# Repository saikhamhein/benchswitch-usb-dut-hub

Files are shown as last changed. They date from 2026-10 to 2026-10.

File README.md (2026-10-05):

# BenchSwitch USB DUT Hub

A four-port USB 2.0 DUT hub for embedded firmware development and automated hardware testing.

BenchSwitch was born from a practical need in agentic firmware development: let the development workflow power-cycle a device instead of waiting for someone to unplug it. The design combines a USB2514B hub controller with individually switched downstream power, targeting host control through tools such as `uhubctl`.

**Prototype: hardware testing is pending.** See the [build guide](doc/BUILD.md), [design constraints](doc/DESIGN_CONSTRAINTS.md) and [bring-up checklist](doc/BRINGUP.md) before building or powering a board.

## Hardware

- Four USB-A DUT ports and one USB-B upstream connection
- Per-port CH217A power switching and overcurrent signalling
- Regulated 12–24 V DC input with buck conversion
- Design targets: 1 A per port, 2 A shared DUT current
- 95 × 80 mm, four-layer PCB
- KiCad 10.0.6 sources; 131 fitted components across 41 catalog groups

## Build

Open [BenchSwitch_USB_DUT_Hub.kicad_pro](PCB/BenchSwitch_USB_DUT_Hub.kicad_pro) in KiCad 10.0.6.

- [Schematic](doc/PCB_Schematic_R5_LCSC.pdf) and [assembly drawing](doc/PCB_Assembly_R5_LCSC.pdf)
- [Gerber ZIP](manufacturing/R5_LCSC/DIN_USB_Hub_A8_R5_LCSC_Gerber.zip)
- [Exact component BOM](manufacturing/R5_LCSC/assembly/BOM_exact_per_reference.csv) and [per-board procurement list](manufacturing/R5_LCSC/LCSC_PROCUREMENT_PER_BOARD.csv)

With Python 3.9+, verify the release files or export to a new directory:

```sh
python manufacturing/tools/verify_release.py
python manufacturing/tools/export_manufacturing.py --output build/manufacturing
```

## Files

- `PCB/`: native design, symbols, footprints and models
- `manufacturing/`: fabrication files, BOM and build tools
- `doc/`: drawings, assembly guidance and test procedures

[CAD verification](doc/VERIFICATION.json) · [Third-party notices and optional model downloads](doc/THIRD_PARTY.md)

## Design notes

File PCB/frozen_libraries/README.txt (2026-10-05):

Frozen library definitions for this design

Only the symbol and footprint definitions used by the reviewed design are included. Project-local library entries deliberately bind these names to the frozen copies, avoiding unintended changes when opening the project with KiCad 10.0.6.

Do not bulk-update the existing footprints or symbols from new global libraries merely to migrate file formats. When adding new parts, extend these frozen libraries deliberately or use a separate library name. The complete standard catalog is not included here.

Native board geometry and embedded schematic symbols remain authoritative. The applicable KiCad library copyright and license notices are included alongside these files.

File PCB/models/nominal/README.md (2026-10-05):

# Nominal component models

These drawing-derived models represent R5-LCSC component packages and terminal datums. Cosmetic features, internal connector contacts and production markings are simplified. They are not manufacturer-certified CAD or maximum-clearance envelopes.

The public PCB retains its circuit, copper, placement and selected parts. Optional Phoenix and Wurth vendor visuals were omitted from this release because redistribution rights were not established. This affects the 3D view only: the Phoenix input terminal and four ordered XUNPU USB-A connectors remain in the PCB and BOM.

Use purchased-part dimensions and the build/bring-up requirements for physical checks. See [third-party notes](../../../doc/THIRD_PARTY.md).

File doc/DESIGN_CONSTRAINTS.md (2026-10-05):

# BenchSwitch USB DUT Hub: design constraints

This summarizes the retained **R5-LCSC prototype** design basis. Preserve its circuit, placement, copper, drills and frozen manufacturing data. CAD integrity checks and component screens are not measured electrical/thermal qualification. The target remains **1 A per port, 2 A shared DUT current, regulated 12–24 V input**.

## Preserve the electrical layout

- Keep continuous inner ground planes and anchored outer ground fills; do not split digital and buck grounds.
- Preserve local input-bypass return to GND/exposed pad, six external regulator thermal vias, compact switch-node copper, short bootstrap return and quiet feedback return. The external-via arrangement does not inherit the vendor's under-exposed-pad reference-board thermal resistance.
- Preserve broad raw-output and protected-supply manifolds, the lower distribution bus, 2 mm right-edge feed and parallel layer transfers. Narrow sensing/bias/package escapes are not substitutes for the main high-current path.
- Keep the local 100 nF port-switch input bypasses and four nominal 10 µF input capacitors. Preserve the crystal's 1/3 resonator and 2/4 ground mapping and the selected 2.0 × 1.2 mm lands.
- Preserve USB data geometry and its eleven `USB_ESCAPE` rule areas. The reviewed outer-ground clearance was at least 0.500 mm to data tracks; the upstream through-hole data pads have approximately 0.450 mm minimum clearance. This is geometry evidence, not controlled-impedance or signal-integrity certification.
- Both 0.30/0.50 mm and 0.30/0.60 mm drill/land vias exist. The smaller lands have 0.10 mm nominal annular rings; do not represent all vias as 0.60 mm lands.

## Exact sourcing constraints

Use `PCB/SELECTED_COMPONENTS.json` and the frozen BOM for all references. The five R5-LCSC replacement groups cover 30 fitted references without changing their electrical connections or physical placement:

- Ordinary 10 kΩ group: **Yageo RC0603FR-0710KL / C98220**, 15 resistors, 1%, 0603, 0.1 W at 70 °C, ±100 ppm/°C. These do not replace tighter-tolerance feedback resistors; apply normal power/temperature derating.
- C20/C27: **Yageo CC0402KRX7R8BB104 / C105883**, 100 nF, 25 V, ±10%, X7R, 0402. C20 bypasses 3V3 and C27 HOST_VBUS; these parts are not the 24 V input capacitors or raw-output bank.
- Q11–Q14: **onsemi MMBT3904LT1G / C81464**, SOT-23 NPN, pin 1 base / 2 emitter / 3 collector, 40 V, 200 mA continuous. Emitters are grounded; 10 kΩ collector pullups to 5V_SYS and 10 kΩ base resistors/100 kΩ pulldowns are retained. Normal collector current is approximately 0.5 mA.
- C64–C69/C82–C83: **Samsung CL31B106KBHNFNE / C913957**, eight 10 µF/50 V/±10%/X7R/1206 ceramics. Keep the Samsung lands and the three Aishi 220 µF/50 V bulk capacitors. Nominally similar capacitance, voltage and package labels alone do not qualify alternatives.
- L6: **MetalLions MNR8065T100MT / C18222125**, 10 µH ±20%. The retained Sunlord-named footprint is a compatible land/envelope, not MetalLions-supplied CAD: two 2.2 × 7.5 mm pads with 3.8 mm inner gap; body maximum 8.3 × 8.3 × 6.5 mm.

J11–J14 remain XUNPU USB-231-ARY / C720525. A visual connector model must not become a BOM substitution.

## Output-capacitor screen

The selected Samsung part has the same 141-point typical DC-bias dataset as the prior CL31B106KBHNNNE. At 5.1 V, interpolated typical capacitance is 8.4357 µF per part. Eight parts multiplied by 0.90 tolerance, 0.85 temperature and 0.85 engineering reserve give **43.8826 µF**. The bias data are typical 25 °C, 1 kHz, 1 Vrms reference data; the reserve is an assumption. The result is voltage-dependent, not a universal minimum-capacitance or transient guarantee. The complete ceramic/polymer network still requires loop and load-release tests.

Do not automatically substitute TDK CGA5L1X7R1H106KT0Y0N or a generic 10 µF/50 V/X7R/1206. Exact ordering-code equivalence, bias behavior, lands and maximum body clearance require review.

## Inductor and fault screen

The selected MetalLions row specifies 44 mΩ maximum DCR and 13 MHz minimum SRF. Its published **8.00 A saturation / 3.20 A heat** entries appear under manufacturer **Max.** headings and must not be relabeled as guaranteed minima; 8.90/3.70 A are typical. Test data are at 20 °C: saturation is about 30% inductance drop and heat current about 40 °C rise. Operating range is −40 to +125 °C including self-heating. No guaranteed hot saturation or L(T,I) lower bound is established.

The SCT2433 high-side peak limit at 24 V is 4.25/5.00/5.75 A minimum/typical/maximum. A screening case uses 5.088 V output, 2.204 A total converter load and 479.4 kHz (510 kHz × 0.94). At assumed 4.48 µH, ideal CCM ripple gives approximately **3.137 A peak and 2.269 A RMS**. The 4.48 µH includes tolerance and assumed temperature/bias factors, not a guaranteed inductance bound. Current-limit delay, overshoot, core/AC loss and board thermal effects remain unbounded by that calculation; hot overload and normal-load testing are required.

Do not substitute the shorter SWPA8040S100MT or MNR8040T100MT merely because the pads fit: their published 3.6 A saturation rating is below the regulator fault-limit range. A different larger inductor requires its own primary-data, footprint and routing review. Component screens cannot certify hot fault immunity, loop stability or mounting-temperature limits.

## Verification boundary

Fresh KiCad 10.0.6 checks of the final sources on 5 October 2026 reported zero ERC findings, zero DRC violations, zero unconnected items and zero schematic-parity findings under inherited settings, including seven disabled DRC and four disabled ERC check types. Cleanup changed project naming, synchronized the embedded/source USB-A default-footprint metadata and removed optional 3D bindings; electrical connections, placed parts, copper and frozen manufacturing payloads were preserved. These checks do not establish actual connector fit, board temperatures, voltage transients, automatic-placement calibration or production qualification. Revalidate any hardware change and complete [prototype bring-up](BRINGUP.md).

### Configured checks excluded from the passing result

The [source-hash-bound verification summary](VERIFICATION.json) records the actual KiCad 10.0.6 result. The following check types were ignored; zero findings does not claim these checks passed:

- ERC: `single_global_label`, `four_way_junction`, `simulation_model_issue`, `footprint_filter`.
- DRC: `missing_courtyard`, `track_not_centered_on_via`, `tuning_profile_track_geometries`, `footprint_filters_mismatch`, `pth_inside_courtyard`, `npth_inside_courtyard`, `footprint_type_mismatch`.

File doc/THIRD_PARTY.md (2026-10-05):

# Third-party and component-model notices

The native PCB and schematic are the design sources. 3D models are visual aids; they do not establish part interchangeability, physical fit, clearance or electrical qualification.

## KiCad libraries

The frozen symbols and footprints include KiCad-derived material. The KiCad community attribution and full CC-BY-SA 4.0 terms with the electronic-design exception are retained in:

- [Symbol notices](../PCB/frozen_libraries/kicad-symbols-COPYRIGHT.txt)
- [Footprint notices](../PCB/frozen_libraries/kicad-footprints-COPYRIGHT.txt)

These notices also apply to KiCad-derived portions of custom footprints, including the AOS TO-252 and Samsung 1206 adaptations. Custom library naming does not imply that every definition is entirely original. Preserve attribution and applicable share-alike obligations when redistributing library material. The electronic-design exception is stated in the included notices; it is not a blanket relicensing of a library collection.

## KiCad 3D assets

Keep the copyright and licensing headers embedded in each retained STEP file.

- `D_SMC.step` and `D_SOD-123F.step` carry **GPL-3.0-or-later** with an electronic-design exception. The [GPL-3.0 text](../PCB/3d_models/GPL-3.0.txt) accompanies them. Their embedded exception says that embedding the symbol or unaltered portions into a design does not by itself make the resulting design GPL-covered; it does not invalidate other reasons the design may be covered. Their exact exception text remains in each model.
- Other retained KiCad package STEP files carry their embedded **CC-BY-SA 4.0 with electronic-design exception** notices. The full CC-BY-SA terms are included in the library notices above.

The retained files are not relicensed by this project. Frozen footprint templates were modified only to remove inherited nonlocal 3D-model references; the Phoenix custom footprint also has its optional vendor-model bindings removed. Footprint pads and other 2D geometry are unchanged. The USB-A default footprint name was synchronized in the source library and embedded schematic symbol to the retained XUNPU footprint already used by all four placed USB-A connectors; symbol pin definitions and placed instance footprints are unchanged.

## Project-created models

Nominal and display models are simplified, drawing-derived package geometry rather than manufacturer-certified solids. Features such as internal contacts, draft, markings and finish may be omitted. Use component datasheets and physical measurements for engineering decisions.

## Omitted optional vendor CAD

The public release excludes the optional Wurth USB-A and Phoenix terminal/mating-plug vendor solids, their PCB/footprint model bindings and populated STEP aggregates. Redistribution rights for those recovered solids were not established for this public package. The native 2D footprint pads, copper, placement, component identities and frozen manufacturing payloads remain unchanged.

Consequently, those components may be absent from a 3D view. The purchased USB-A parts remain **XUNPU USB-231-ARY / C720525**, and the input terminal and mating plug remain the Phoenix parts specified in the exact BOM/accessory list. No replacement-part compatibility is claimed.

## Project license

No project-wide open-source license has been selected. Public availability does not replace third-party terms or grant a new blanket license to the original project material.

## Optional vendor-model downloads

The electrical project opens and the supplied fabrication package can be used without these optional 3D visuals. For a local visualization, obtain CAD directly from the manufacturer and follow the terms shown with the download:

- [Wurth WR-USB Standard](https://www.we-online.com/en/components/products/INPUT_OUTPUT_WR_USB_STANDARD): select **614004190021** and its STP download. This is a visualization surrogate, not the ordered XUNPU USB-A part.
- [Phoenix Contact MSTBA 2,5/2-G-5,08, 1757242](https://www.phoenixcontact.com/en-us/products/pcb-header-mstba-25-2-g-508-1757242): product CAD/downloads for the PCB header; [original model download](https://www.phoenixcontact.com/product/product/MTc1NzI0Mg/downloads/7966887?_realm=us&_locale=en-US).
- [Phoenix Contact MSTB 2,5/2-ST-5,08, 1757019](https://www.phoenixcontact.com/en-us/products/pcb-plug-mstb-25-2-st-508-1757019): product CAD/downloads for the mating plug; [original model download](https://www.phoenixcontact.com/product/product/MTc1NzAxOQ/downloads/8194525?_realm=us&_locale=en-US).

Add any locally downloaded file through KiCad's footprint 3D-model settings and check orientation, origin and alignment yourself. A newer vendor download may differ from the former private model; no alignment or interchangeability is assumed. Keep private downloads outside the published source tree unless redistribution permission is established. Do not modify pads, placement, copper or the frozen Gerbers just to improve a render.

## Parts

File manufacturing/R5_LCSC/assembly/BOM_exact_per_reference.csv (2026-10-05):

Reference | Value | Footprint | MPN | LCSC
C1 | 4.7u / 16V | Capacitor_SMD:C_0805_2012Metric | 0805B475K160NT | C880382
C2 | 4.7u / 16V | Capacitor_SMD:C_0805_2012Metric | 0805B475K160NT | C880382
C4 | 4.7u / 16V | Capacitor_SMD:C_0805_2012Metric | 0805B475K160NT | C880382
C10 | 100nF | Capacitor_SMD:C_0603_1608Metric | CC0603KRX7R9BB104 | C14663
C11 | 100nF | Capacitor_SMD:C_0603_1608Metric | CC0603KRX7R9BB104 | C14663
C12 | 33pF C0G | Capacitor_SMD:C_0603_1608Metric | CL10C330JB8NNNC | C1663
C13 | 33pF C0G | Capacitor_SMD:C_0603_1608Metric | CL10C330JB8NNNC | C1663
C14 | 100nF | Capacitor_SMD:C_0603_1608Metric | CC0603KRX7R9BB104 | C14663
C20 | 100nF | Capacitor_SMD:C_0402_1005Metric | CC0402KRX7R8BB104 | C105883
C21 | 100nF | Capacitor_SMD:C_0603_1608Metric | CC0603KRX7R9BB104 | C14663
C22 | 100nF | Capacitor_SMD:C_0603_1608Metric | CC0603KRX7R9BB104 | C14663
C23 | 100nF | Capacitor_SMD:C_0603_1608Metric | CC0603KRX7R9BB104 | C14663
C24 | 100nF | Capacitor_SMD:C_0603_1608Metric | CC0603KRX7R9BB104 | C14663
C25 | 100nF | Capacitor_SMD:C_0603_1608Metric | CC0603KRX7R9BB104 | C14663
C26 | 4.7uF / 16V | Capacitor_SMD:C_0805_2012Metric | 0805B475K160NT | C880382
C27 | 100nF / 25V | Capacitor_SMD:C_0402_1005Metric | CC0402KRX7R8BB104 | C105883
C60 | 4.7u / 50V | Capacitor_SMD:C_1206_3216Metric | 1206B475K500NT | C29823
C61 | 4.7u / 50V | Capacitor_SMD:C_1206_3216Metric | 1206B475K500NT | C29823
C63 | 100n / 50V | Resistor_SMD:R_0603_1608Metric | CC0603KRX7R9BB104 | C14663
C64 | 10u / 50V | DUT_Custom:Samsung_CL31_1206 | CL31B106KBHNFNE | C913957
C65 | 10u / 50V | DUT_Custom:Samsung_CL31_1206 | CL31B106KBHNFNE | C913957
C66 | 10u / 50V | DUT_Custom:Samsung_CL31_1206 | CL31B106KBHNFNE | C913957
C67 | 10u / 50V | DUT_Custom:Samsung_CL31_1206 | CL31B106KBHNFNE | C913957
C68 | 10u / 50V | DUT_Custom:Samsung_CL31_1206 | CL31B106KBHNFNE | C913957
C69 | 10u / 50V | DUT_Custom:Samsung_CL31_1206 | CL31B106KBHNFNE | C913957
C70 | 100n / 50V | Resistor_SMD:R_0603_1608Metric | CC0603KRX7R9BB104 | C14663
C71 | 100n / 50V | Capacitor_SMD:C_0603_1608Metric | CC0603KRX7R9BB104 | C14663
C72 | 4.7u / 50V | Capacitor_SMD:C_1206_3216Metric | 1206B475K500NT | C29823
C73 | 47u / 50V | Capacitor_THT:CP_Radial_D6.3mm_P2.50mm | SPZ1HM470E08O00RAXXX | C122243
C74 | 220u / 50V polymer | Capacitor_THT:CP_Radial_D10.0mm_P5.00mm | SPZ1HM221G12O00RAXXX | C2691846
C76 | 220u / 50V polymer | Capacitor_THT:CP_Radial_D10.0mm_P5.00mm | SPZ1HM221G12O00RAXXX | C2691846
C77 | 220u / 50V polymer | Capacitor_THT:CP_Radial_D10.0mm_P5.00mm | SPZ1HM221G12O00RAXXX | C2691846
C80 | 4.7u / 50V | Capacitor_SMD:C_1206_3216Metric | 1206B475K500NT | C29823
C82 | 10u / 50V | DUT_Custom:Samsung_CL31_1206 | CL31B106KBHNFNE | C913957
C83 | 10u / 50V | DUT_Custom:Samsung_CL31_1206 | CL31B106KBHNFNE | C913957
C101 | 100nF | Capacitor_SMD:C_0603_1608Metric | CC0603KRX7R9BB104 | C14663
C102 | 10uF / 16V | Capacitor_SMD:C_0805_2012Metric | CC0805KKX7R7BB106 | C326595
C103 | 220uF / 10V | Capacitor_THT:CP_Radial_D6.3mm_P2.50mm | ERS1AM221E11OT | C106640
C104 | 100nF | Capacitor_SMD:C_0603_1608Metric | CC0603KRX7R9BB104 | C14663
C201 | 100nF | Capacitor_SMD:C_0603_1608Metric | CC0603KRX7R9BB104 | C14663
C202 | 10uF / 16V | Capacitor_SMD:C_0805_2012Metric | CC0805KKX7R7BB106 | C326595
C203 | 220uF / 10V | Capacitor_THT:CP_Radial_D6.3mm_P2.50mm | ERS1AM221E11OT | C106640
C204 | 100nF | Capacitor_SMD:C_0603_1608Metric | CC0603KRX7R9BB104 | C14663
C301 | 100nF | Capacitor_SMD:C_0603_1608Metric | CC0603KRX7R9BB104 | C14663
C302 | 10uF / 16V | Capacitor_SMD:C_0805_2012Metric | CC0805KKX7R7BB106 | C326595
C303 | 220uF / 10V | Capacitor_THT:CP_Radial_D6.3mm_P2.50mm | ERS1AM221E11OT | C106640
C304 | 100nF | Capacitor_SMD:C_0603_1608Metric | CC0603KRX7R9BB104 | C14663
C401 | 100nF | Capacitor_SMD:C_0603_1608Metric | CC0603KRX7R9BB104 | C14663
C402 | 10uF / 16V | Capacitor_SMD:C_0805_2012Metric | CC0805KKX7R7BB106 | C326595
C403 | 220uF / 10V | Capacitor_THT:CP_Radial_D6.3mm_P2.50mm | ERS1AM221E11OT | C106640
C404 | 100nF | Capacitor_SMD:C_0603_1608Metric | CC0603KRX7R9BB104 | C14663
D6 | SMCJ24CA / bidir | Diode_SMD:D_SMC | SMCJ24CA-13-F | C135155
D7 | 12V gate clamp | Diode_SMD:D_SOD-123F | BZT52H-C12,115 | C282531
D8 | STPS5L60S | Diode_SMD:D_SMC | STPS5L60S | C140620
D101 | GREEN / VBUS | DUT_Custom:LED_LiteOn_LTST-S270KGKT_SideView | LTST-S270KGKT | C125113
D201 | GREEN / VBUS | DUT_Custom:LED_LiteOn_LTST-S270KGKT_SideView | LTST-S270KGKT | C125113
D301 | GREEN / VBUS | DUT_Custom:LED_LiteOn_LTST-S270KGKT_SideView | LTST-S270KGKT | C125113
D401 | GREEN / VBUS | DUT_Custom:LED_LiteOn_LTST-S270KGKT_SideView | LTST-S270KGKT | C125113
F1 | 5 A / Nano2 | Fuse:Fuse_Littelfuse-NANO2-451_453 | 0451005.MRL | C48467
J1 | 12-24V DC / pluggable | DUT_Custom:Phoenix_MSTBA_1757242_2pos_P5.08 | 1757242 | C90074
J2 | XUNPU USB-B10-BRW | DUT_Custom:XUNPU_USB_B10_BRW | USB-B10-BRW | C720549
J11 | USB-231-ARY | DUT_Custom:XUNPU_USB_231_ARY | USB-231-ARY | C720525
J12 | USB-231-ARY | DUT_Custom:XUNPU_USB_231_ARY | USB-231-ARY | C720525
J13 | USB-231-ARY | DUT_Custom:XUNPU_USB_231_ARY | USB-231-ARY | C720525
J14 | USB-231-ARY | DUT_Custom:XUNPU_USB_231_ARY | USB-231-ARY | C720525
L6 | 10uH / MNR8065T | DUT_Custom:Sunlord_SWPA8065S | MNR8065T100MT | C18222125
Q6 | AOD409 / -60V P-MOS | DUT_Custom:AOS_AOD409_TO252 | AOD409 | C36220
Q11 | MMBT3904 | Package_TO_SOT_SMD:SOT-23 | MMBT3904LT1G | C81464
Q12 | MMBT3904 | Package_TO_SOT_SMD:SOT-23 | MMBT3904LT1G | C81464
Q13 | MMBT3904 | Package_TO_SOT_SMD:SOT-23 | MMBT3904LT1G | C81464
Q14 | MMBT3904 | Package_TO_SOT_SMD:SOT-23 | MMBT3904LT1G | C81464
R1 | 100k 1% | Resistor_SMD:R_0603_1608Metric | 0603WAF1003T5E | C25803
R2 | 100k 1% | Resistor_SMD:R_0603_1608Metric | 0603WAF1003T5E | C25803
R10 | 100k | Resistor_SMD:R_0603_1608Metric | 0603WAF1003T5E | C25803
R11 | 100k | Resistor_SMD:R_0603_1608Metric | 0603WAF1003T5E | C25803
R12 | 100k | Resistor_SMD:R_0603_1608Metric | 0603WAF1003T5E | C25803
R13 | 100k | Resistor_SMD:R_0603_1608Metric | 0603WAF1003T5E | C25803
R14 | 12k 1% | Resistor_SMD:R_0603_1608Metric | 0603WAF1202T5E | C22790
R15 | 10k | Resistor_SMD:R_0603_1608Metric | RC0603FR-0710KL | C98220
R60 | 10k | Resistor_SMD:R_0603_1608Metric | RC0603FR-0710KL | C98220
R61 | 100k 1% | Resistor_SMD:R_0603_1608Metric | 0603WAF1003T5E | C25803
R62 | 13k 1% | Resistor_SMD:R_0603_1608Metric | 0603WAF1302T5E | C22797
R65 | 53.6k 0.1% | Resistor_SMD:R_0603_1608Metric | ERA-3AEB5362V | C2074540
R66 | 10k 0.1% | Resistor_SMD:R_0603_1608Metric | RT0603BRD0710KL | C95204
R69 | 6.8k 0.1% | Resistor_SMD:R_0603_1608Metric | RT0603BRD076K8L | C861539
R70 | 2k 0.1% | Resistor_SMD:R_0603_1608Metric | PTFR0603B2K00P9 | C328425
R71 | 10k bleed | Resistor_SMD:R_0603_1608Metric | RC0603FR-0710KL | C98220
R72 | 100R | Resistor_SMD:R_0603_1608Metric | 0603WAF1000T5E | C22775
R101 | 100k | Resistor_SMD:R_0603_1608Metric | 0603WAF1003T5E | C25803
R102 | 10k | Resistor_SMD:R_0603_1608Metric | RC0603FR-0710KL | C98220
R103 | 51k 1% | Resistor_SMD:R_0603_1608Metric | 0603WAF5102T5E | C23196
R104 | 470R / 0.5W | Resistor_SMD:R_0805_2012Metric | ERJ-P06F4700V | C441978
R105 | 4.7k 1% | Resistor_SMD:R_0603_1608Metric | 0603WAF4701T5E | C23162
R106 | 10k 1% | Resistor_SMD:R_0603_1608Metric | RC0603FR-0710KL | C98220
R107 | 10k 1% | Resistor_SMD:R_0603_1608Metric | RC0603FR-0710KL | C98220
R201 | 100k | Resistor_SMD:R_0603_1608Metric | 0603WAF1003T5E | C25803
R202 | 10k | Resistor_SMD:R_0603_1608Metric | RC0603FR-0710KL | C98220
R203 | 51k 1% | Resistor_SMD:R_0603_1608Metric | 0603WAF5102T5E | C23196
R204 | 470R / 0.5W | Resistor_SMD:R_0805_2012Metric | ERJ-P06F4700V | C441978
R205 | 4.7k 1% | Resistor_SMD:R_0603_1608Metric | 0603WAF4701T5E | C23162
R206 | 10k 1% | Resistor_SMD:R_0603_1608Metric | RC0603FR-0710KL | C98220
R207 | 10k 1% | Resistor_SMD:R_0603_1608Metric | RC0603FR-0710KL | C98220
R301 | 100k | Resistor_SMD:R_0603_1608Metric | 0603WAF1003T5E | C25803
R302 | 10k | Resistor_SMD:R_0603_1608Metric | RC0603FR-0710KL | C98220
R303 | 51k 1% | Resistor_SMD:R_0603_1608Metric | 0603WAF5102T5E | C23196
R304 | 470R / 0.5W | Resistor_SMD:R_0805_2012Metric | ERJ-P06F4700V | C441978
R305 | 4.7k 1% | Resistor_SMD:R_0603_1608Metric | 0603WAF4701T5E | C23162
R306 | 10k 1% | Resistor_SMD:R_0603_1608Metric | RC0603FR-0710KL | C98220
R307 | 10k 1% | Resistor_SMD:R_0603_1608Metric | RC0603FR-0710KL | C98220
R401 | 100k | Resistor_SMD:R_0603_1608Metric | 0603WAF1003T5E | C25803
R402 | 10k | Resistor_SMD:R_0603_1608Metric | RC0603FR-0710KL | C98220
R403 | 51k 1% | Resistor_SMD:R_0603_1608Metric | 0603WAF5102T5E | C23196
R404 | 470R / 0.5W | Resistor_SMD:R_0805_2012Metric | ERJ-P06F4700V | C441978
R405 | 4.7k 1% | Resistor_SMD:R_0603_1608Metric | 0603WAF4701T5E | C23162
R406 | 10k 1% | Resistor_SMD:R_0603_1608Metric | RC0603FR-0710KL | C98220
R407 | 10k 1% | Resistor_SMD:R_0603_1608Metric | RC0603FR-0710KL | C98220
U1 | AP2112K-3.3 | Package_TO_SOT_SMD:SOT-23-5 | AP2112K-3.3TRG1 | C51118
U2 | USBLC6-2SC6 | Package_TO_SOT_SMD:SOT-23-6 | USBLC6-2SC6 | C7519
U3 | USB2514B-AEZC-TR | Package_DFN_QFN:QFN-36-1EP_6x6mm_P0.5mm_EP3.7x3.7mm | USB2514B-AEZC-TR | C16251
U4 | APX803S00-31SR | DUT_Custom:Diodes_APX803S_SR_SOT23 | APX803S00-31SR-7 | C2067620
U6 | SCT2433STER | DUT_Custom:SCT2433_ESOP8 | SCT2433STER | C509399
U7 | ETA7014S2G | Package_TO_SOT_SMD:SOT-23-6 | ETA7014S2G | C7465500
U11 | CH217A | Package_TO_SOT_SMD:SOT-23-6 | CH217A | C54973763
U12 | CH217A | Package_TO_SOT_SMD:SOT-23-6 | CH217A | C54973763
U13 | CH217A | Package_TO_SOT_SMD:SOT-23-6 | CH217A | C54973763
U14 | CH217A | Package_TO_SOT_SMD:SOT-23-6 | CH217A | C54973763
U21 | USBLC6-2SC6 | Package_TO_SOT_SMD:SOT-23-6 | USBLC6-2SC6 | C7519
U22 | USBLC6-2SC6 | Package_TO_SOT_SMD:SOT-23-6 | USBLC6-2SC6 | C7519
U23 | USBLC6-2SC6 | Package_TO_SOT_SMD:SOT-23-6 | USBLC6-2SC6 | C7519
U24 | USBLC6-2SC6 | Package_TO_SOT_SMD:SOT-23-6 | USBLC6-2SC6 | C7519
Y1 | 24MHz / CL20pF | DUT_Custom:YXC_YSX531SL_5032 | XL1EL89CSI-111YLC-24M | C18214302

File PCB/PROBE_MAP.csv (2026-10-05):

Reference | Net | Local_X_mm | Local_Y_down_mm | Pad_diameter_mm | Note
TP1 | /VIN_DC | 92.0 | 10.0 | 1.0 | Use short ground spring
TP10 | 3V3 | 53.8 | 45.0 | 1.0 | Use short ground spring
TP11 | GND | 48.0 | 39.0 | 1.0 | Use short ground spring
TP2 | /VIN_PROTECTED | 78.0 | 28.5 | 1.0 | Use short ground spring
TP3 | /5V_BUCK | 55.5 | 44.0 | 1.0 | Use short ground spring
TP4 | 5V_SYS | 57.0 | 48.0 | 1.0 | Use short ground spring
TP5 | /OV5_SENSE | 64.0 | 41.9 | 1.0 | Use short ground spring
TP6 | /BUCK_FB | 72.2 | 33.0 | 0.4 | High-resistance low-capacitance probe only; prefer rail measurement
TP7 | GND | 73.7 | 29.8 | 1.0 | Use short ground spring
TP8 | GND | 55.0 | 46.6 | 1.0 | Use short ground spring
TP9 | GND | 57.0 | 44.0 | 1.0 | Use short ground spring

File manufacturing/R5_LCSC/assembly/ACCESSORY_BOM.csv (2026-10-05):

MPN | LCSC | Quantity | Description | Price_snapshot_USD | Status
1757019 | C90073 | 1 | Phoenix removable mating plug supplied separately or mated | 0.8795 | Not placed by CPL; confirm delivery handling before purchase

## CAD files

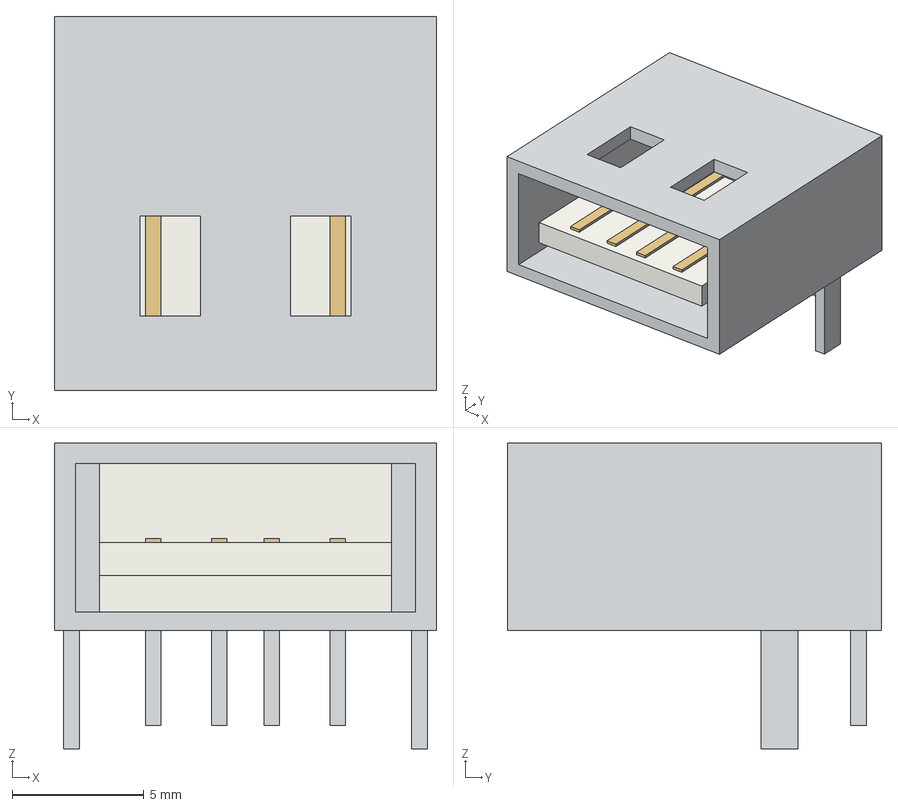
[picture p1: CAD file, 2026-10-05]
PCB/models/display/XUNPU_USB_231_ARY_display.step
14.5 x 14.2 x 11.6 mm
insulator
rear_insulator
contact_1
tail_1
contact_2
tail_2
contact_3
tail_3
contact_4
tail_4
shield_tail_0
shield_tail_1

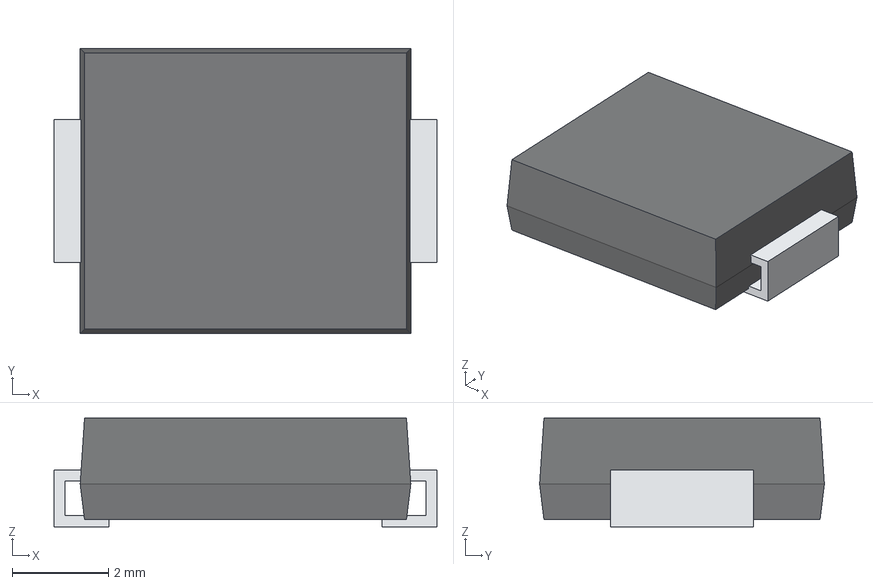
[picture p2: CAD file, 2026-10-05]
PCB/models/nominal/SMCJ24CA_bidir_nominal.step
7.94 x 5.91 x 2.25 mm
Molded_body_no_polarity_band
Terminal_1
Terminal_2

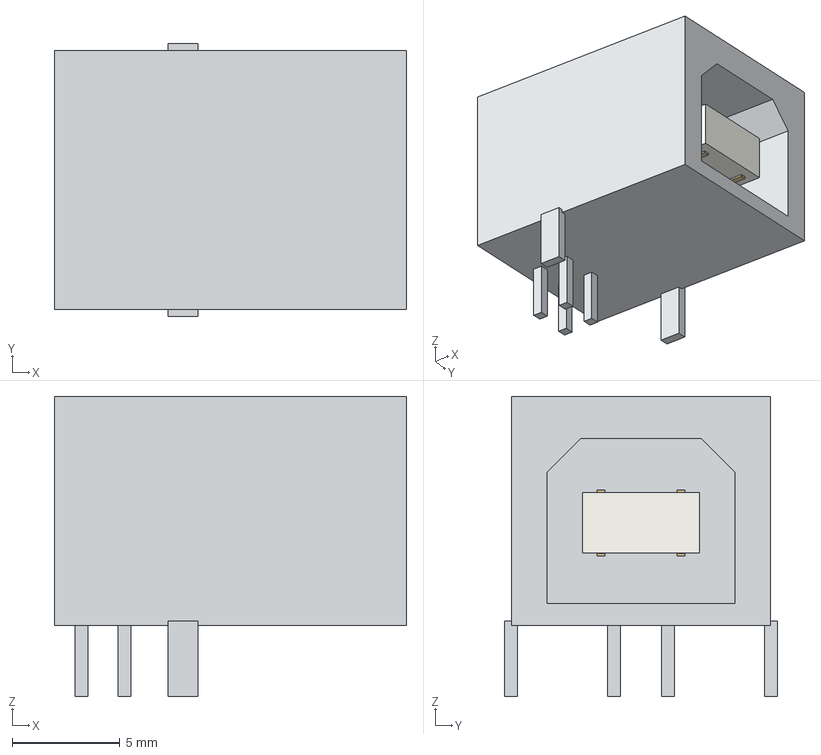
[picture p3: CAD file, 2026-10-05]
PCB/models/display/XUNPU_USB_B10_BRW_display.step
16.3 x 12.6 x 13.9 mm
rear_insulator
central_insulator
tail_1
tail_2
tail_3
tail_4
shield_tail_0
shield_tail_1
contact_1
contact_2
contact_3
contact_4

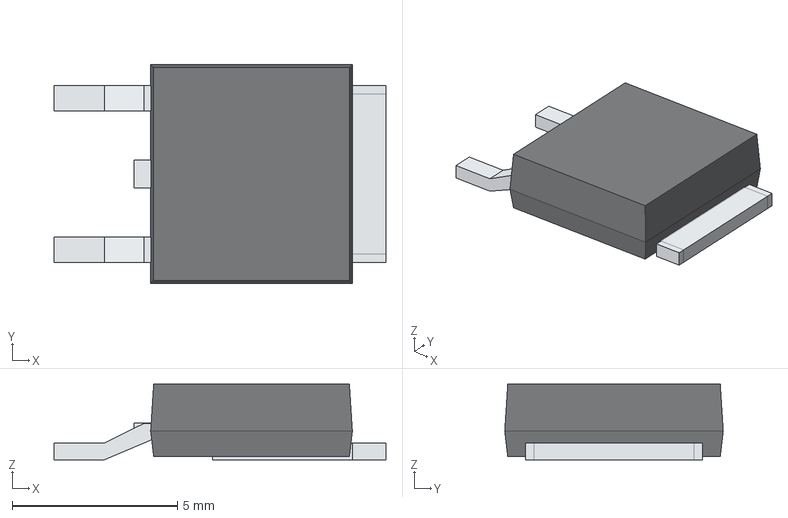
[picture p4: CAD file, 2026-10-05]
PCB/models/nominal/AOD409_TO252_nominal.step
10.0 x 6.60 x 2.29 mm
Molded_body
Drain_tab_2
Gate_1
Source_3
Trimmed_drain_lead_2

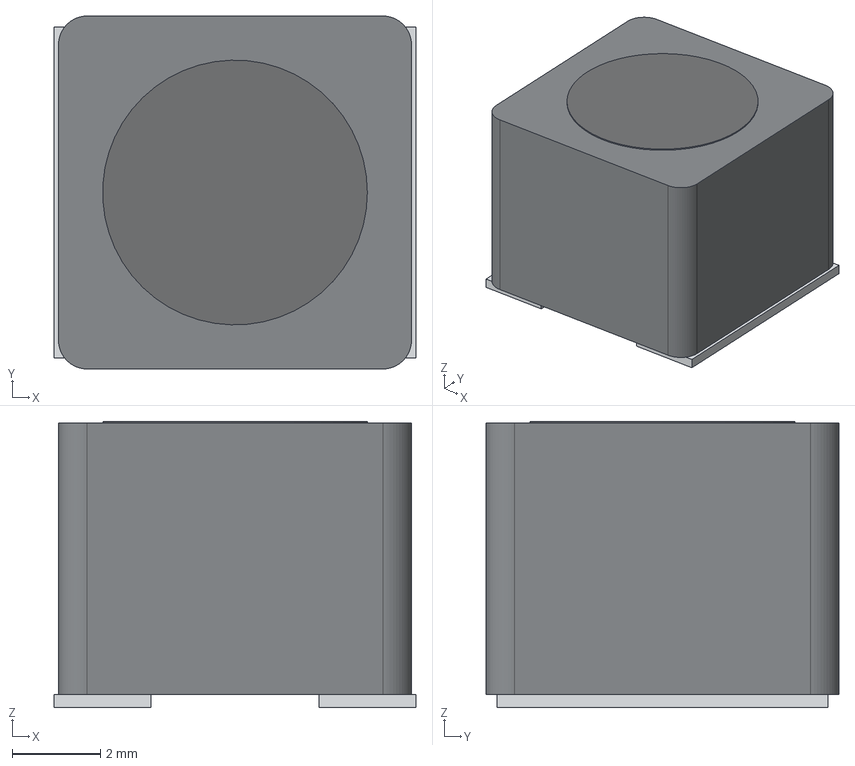
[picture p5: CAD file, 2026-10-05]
PCB/models/display/Sunlord_SWPA8065S_display.step
8.20 x 8.00 x 6.49 mm
ferrite
top_core
termination_1
termination_2

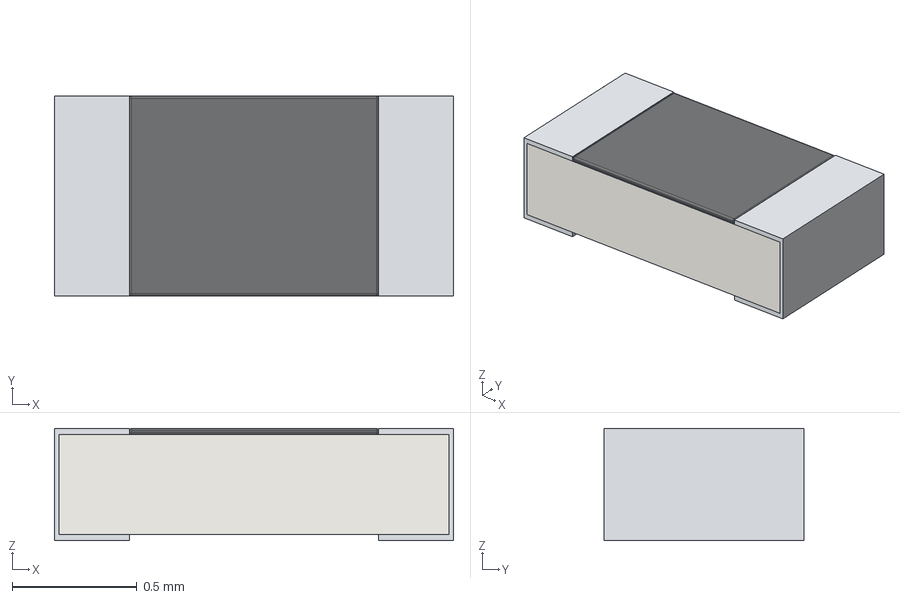
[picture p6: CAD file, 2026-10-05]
PCB/models/nominal/0603WAF_nominal.step
1.60 x 0.8 x 0.45 mm
Alumina_substrate
Resistive_overcoat_no_text
Termination_1
Termination_2

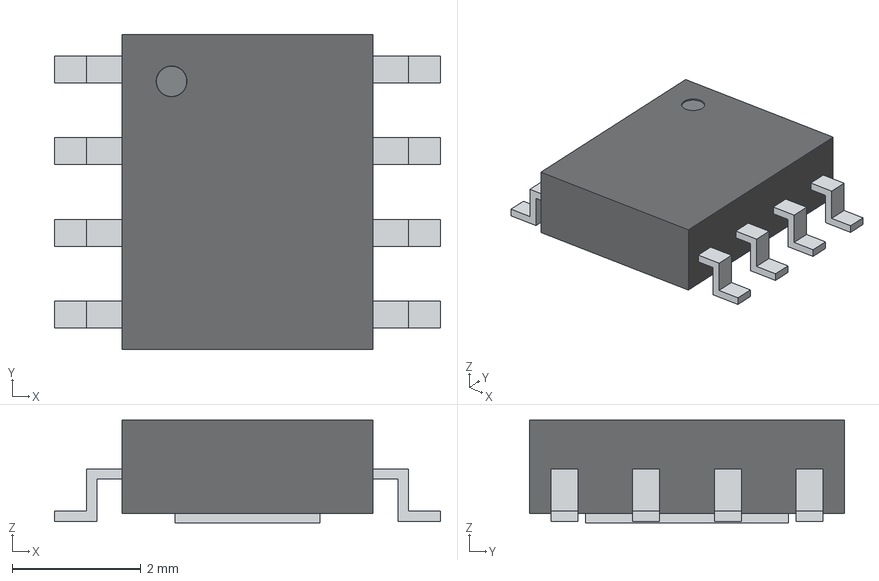
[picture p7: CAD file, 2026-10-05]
PCB/models/display/SCT2433_ESOP8_display.step
6.00 x 4.90 x 1.60 mm
moulding
pin1_recess
exposed_pad
lead_-1_0
lead_-1_1
lead_-1_2
lead_-1_3
lead_1_0
lead_1_1
lead_1_2
lead_1_3

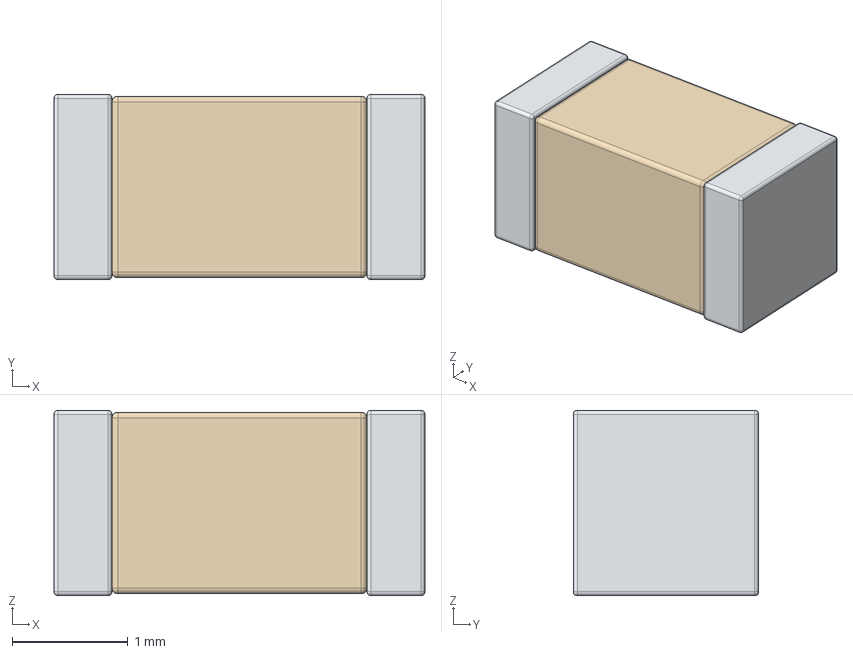
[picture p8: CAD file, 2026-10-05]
PCB/models/nominal/CL31B106KBHNFNE_nominal.step
3.20 x 1.60 x 1.60 mm
Ceramic_nominal
Termination_1
Termination_2

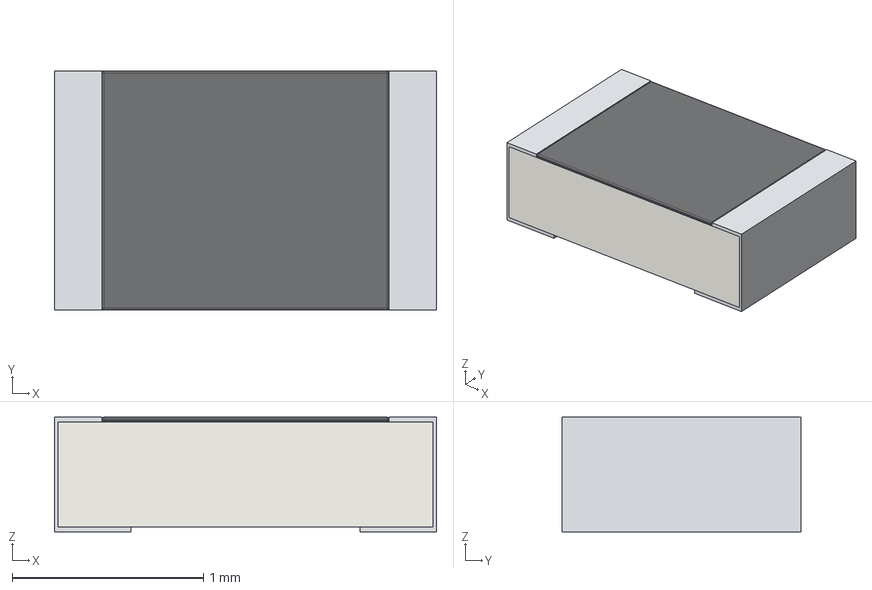
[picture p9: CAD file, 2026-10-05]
PCB/models/nominal/ERJ_P06F4700V_nominal.step
2.00 x 1.25 x 0.6 mm
Alumina_substrate
Resistive_overcoat_no_text
Termination_1
Termination_2

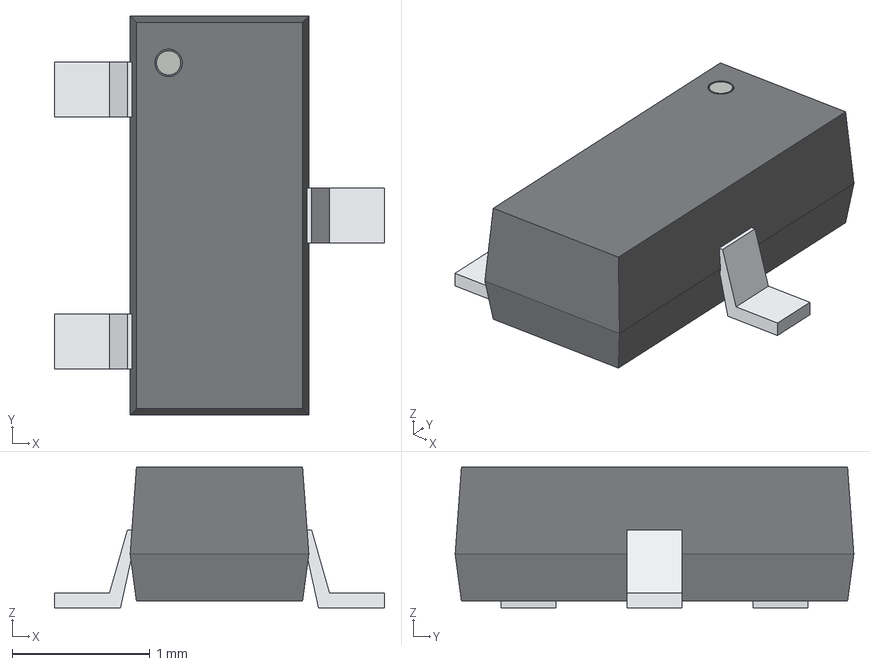
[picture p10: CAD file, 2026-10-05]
PCB/models/nominal/APX803S_SR_nominal.step
2.40 x 2.90 x 1.02 mm
Pin1_orientation_dot_schematic
Molded_body
Lead_1
Lead_2
Lead_3

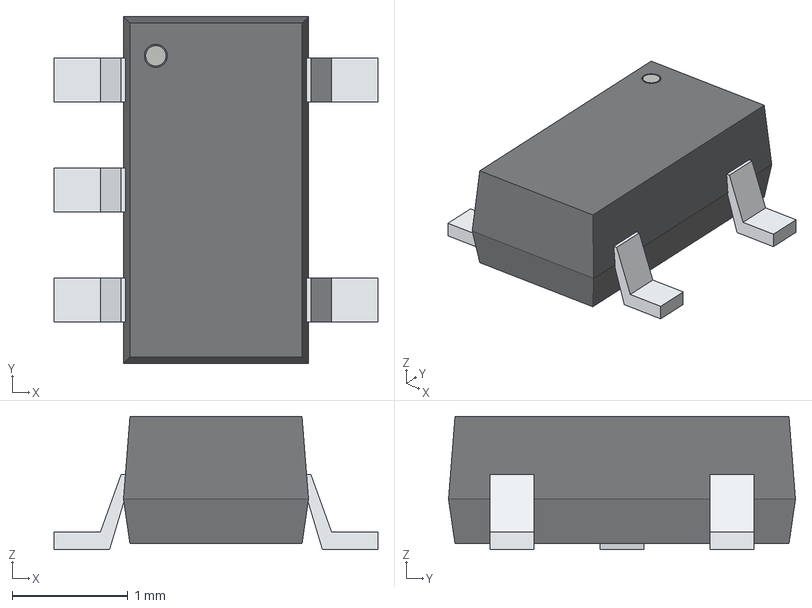
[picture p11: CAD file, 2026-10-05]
PCB/models/nominal/AP2112K_nominal.step
2.80 x 3.00 x 1.15 mm
Pin1_orientation_dot_schematic
Molded_body
Lead_1
Lead_2
Lead_3
Lead_4
Lead_5

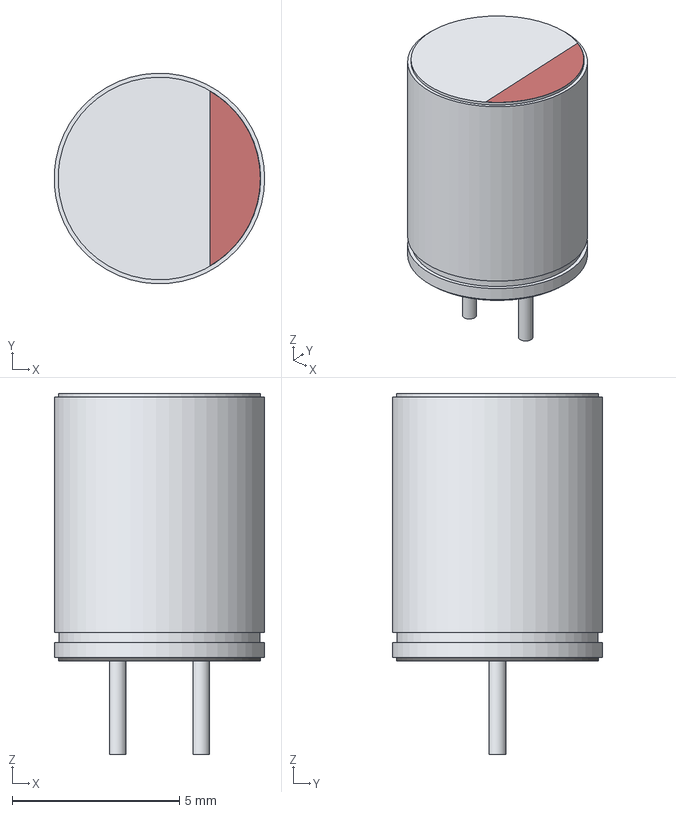
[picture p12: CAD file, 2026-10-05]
PCB/models/nominal/SPZ1HM470E08O00RAXXX_nominal.step
6.29 x 6.30 x 10.8 mm
Aluminum_can
Bottom_bung
Top_lid
Negative_polarity_red_sector
Lead_1_positive
Lead_2_negative

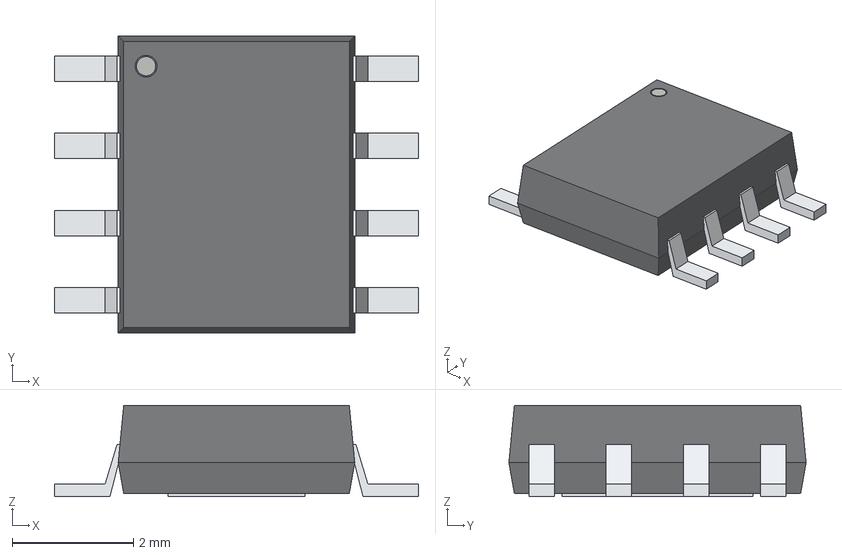
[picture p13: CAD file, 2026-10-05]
PCB/models/nominal/SCT2433STER_ESOP8_nominal.step
6.00 x 4.90 x 1.50 mm
Pin1_orientation_dot_schematic
Molded_body
Thermal_pad_9
Lead_1
Lead_8
Lead_2
Lead_7
Lead_3
Lead_6
Lead_4
Lead_5

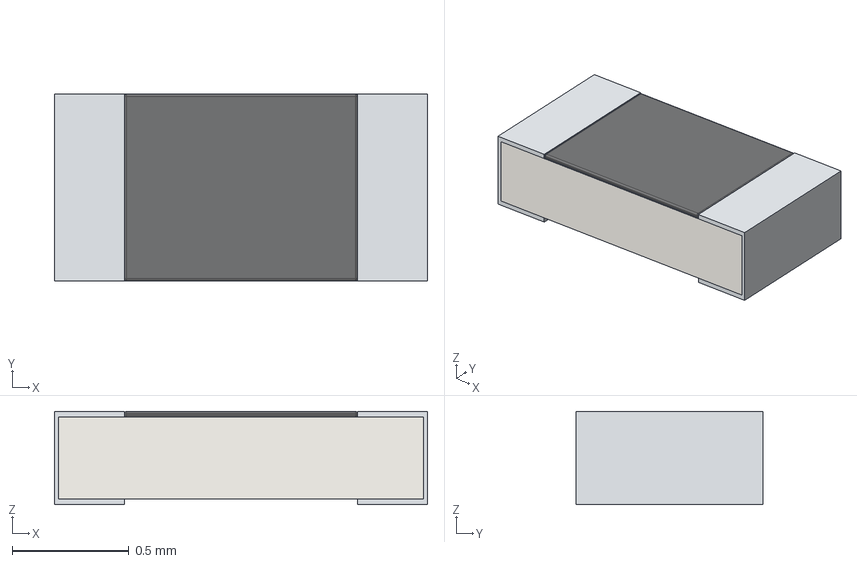
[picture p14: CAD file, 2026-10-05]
PCB/models/nominal/PTFR0603B2K00P9_nominal.step
1.60 x 0.8 x 0.4 mm
Alumina_substrate
Resistive_overcoat_no_text
Termination_1
Termination_2

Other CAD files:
PCB/models/nominal/XUNPU_USB_B10_BRW_nominal.step
PCB/models/nominal/ERA_3AEB5362V_nominal.step
PCB/models/nominal/USBLC6_2SC6_nominal.step
PCB/models/nominal/SPZ1HM221G12O00RAXXX_nominal.step
PCB/models/nominal/0451005_MRL_nominal.step
PCB/models/nominal/0805B475K160NT_nominal.step
PCB/models/nominal/1206B475K500NT_nominal.step
PCB/models/nominal/CC0402KRX7R8BB104_nominal.step
PCB/models/nominal/CC0603KRX7R9BB104_nominal.step
PCB/models/nominal/CC0805KKX7R7BB106_nominal.step
PCB/models/nominal/CH217A_family_nominal.step
PCB/models/nominal/CL10C330JB8NNNC_nominal.step
PCB/models/nominal/ERS1AM221E11OT_nominal.step
PCB/models/nominal/ETA7014S2G_nominal.step
PCB/models/nominal/LTST_S270KGKT_sideview_nominal.step
PCB/models/nominal/MMBT3904LT1G_nominal.step
PCB/models/nominal/MNR8065T100MT_nominal.step
PCB/models/nominal/RC0603_RT0603_nominal.step
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

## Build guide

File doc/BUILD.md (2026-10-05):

# BenchSwitch USB DUT Hub: build

R5-LCSC is a four-port USB 2.0 PCB for self assembly. Its characterization target is **1 A per port and 2 A shared DUT current**, using a regulated **12–24 V DC** bench supply. These are prototype targets, not qualified operating ratings. Read [bring-up](BRINGUP.md) before connecting DUTs.

## Fabrication and parts

Use the frozen R5-LCSC files, whose legacy filenames are retained:

- Bare PCB: `manufacturing/R5_LCSC/DIN_USB_Hub_A8_R5_LCSC_Gerber.zip`
- Fitted component BOM: `manufacturing/R5_LCSC/assembly/JLC_BOM_QUOTE_ONLY.csv`
- Per-board purchasing quantities: `manufacturing/R5_LCSC/LCSC_PROCUREMENT_PER_BOARD.csv`
- Exact selected identities: `PCB/SELECTED_COMPONENTS.json`

Fabrication parameters: **95 × 80 mm, four layers, 1.6 mm, green soldermask, lead-free HASL, standard/default JLC 7628 stackup, 1 oz outer copper and default inner copper**. Do not add paid impedance control, ENIG, Kelvin testing or a small-via option to this build. Minimum via drill is 0.30 mm; copper lands include both 0.50 and 0.60 mm diameters. The 0.50 mm lands have a nominal 0.10 mm annular ring; confirm CAM acceptance of the actual files. Existing USB geometry is unverified for this stackup; no 90-ohm production impedance claim is made.

There are **131 fitted PCB parts in 41 catalog groups**. Add one separate **Phoenix 1757019 / LCSC C90073** mating input plug per completed board. Derive quantities from per-board usage and the intended populated-board count, then round the totals once to current supplier MOQ/multiples. Saved stock and prices are historical; recheck all components before obtaining a new bare-PCB quote. Previous quotes are superseded. No PCBA service is requested; checkout is separate.

No assembly rails are required for self assembly. If a supplier adds rails, prefer left/right; top/bottom rails need a routed separation gap for overhanging USB shells.

## Self assembly and mounting

1. Compare received parts with the exact BOM. Keep DNP parts unpopulated, including optional C106/C206/C306/C406 timing capacitors. Use [design constraints](DESIGN_CONSTRAINTS.md) before considering any substitution.
2. Assemble from native PCB reference designators and pad markings. Check IC pin 1, diode and polarized-capacitor orientation, transistor pinouts, regulator exposed-pad soldering and actual resistor values. Use component-approved soldering processes; inspect for bridges, open joints and damaged pads before power.
3. Confirm connector fit using the purchased connectors and actual cables. J11–J14 are **XUNPU USB-231-ARY / C720525**; Optional Wurth and Phoenix vendor 3D visuals are omitted from this public package; this does not change the ordered parts or 2D pad geometry.
4. Secure the PCB on electrically insulated supports. Ensure screws, washers, inserts and other metal cannot contact or bridge copper on either face, including after cable insertion force or board flex. Verify clearances with the actual hardware before power. Do not operate the board on a conductive surface.
5. With input power removed, wire and mate the Phoenix terminal, checking polarity against the PCB/schematic. Use a current-limited supply for first power; keep valuable DUTs disconnected until the relevant tests pass.

The retained CPL/placement data have unresolved library-origin and rotation calibration issues. They are reference data, not automated-placement approval, and are not needed for bare-PCB ordering or manual assembly.

## Exporting a future revision

Open `PCB/BenchSwitch_USB_DUT_Hub.kicad_pro` in **KiCad 10.0.6** with the repository's local libraries. From the repository root, use `python manufacturing/tools/export_manufacturing.py --output <new-output-directory>` with initialized, writable KiCad configuration. Use a new, non-existing output directory each time; existing directories and symbolic-link output paths are refused to prevent stale files entering a fabrication ZIP. Keep the frozen `manufacturing/R5_LCSC` package unchanged until a separately reviewed revision is intended.

The exporter checks ERC, DRC, schematic parity and exact selected-part/BOM consistency, then creates quote files. Review CAM and every exported package; a newly generated CPL still needs origin/rotation calibration. The final renamed sources were checked with KiCad 10.0.6 on 5 October 2026: zero ERC findings and zero DRC, unconnected-item or schematic-parity findings. These checks retain seven disabled DRC and four disabled ERC check types. The frozen manufacturing payloads were preserved, not replaced by a new export. Export success does not establish physical qualification.

Every remaining board and footprint-library model reference is project-local. Optional vendor solids and inherited global-library 3D references were removed for a self-contained release; footprint pads and native PCB geometry are unchanged. Avoid bulk-updating footprints just to refresh a 3D view.

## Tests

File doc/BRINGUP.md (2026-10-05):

# BenchSwitch USB DUT Hub: prototype bring-up

R5-LCSC target: **regulated 12–24 V DC input; four USB 2.0 ports; 1 A per port and 2 A total DUT load**. Internal board consumption is additional. The input fuse and port current limits do not establish safety with arbitrary adapters or industrial transients. Follow [build and mounting checks](BUILD.md) first.

## Before attaching DUTs

Use a current-limited bench source, suitable dummy loads and appropriately rated instruments. Start with all DUTs disconnected. Inspect polarity, soldering, resistor values, DNP sites and mounting insulation. Stop on unexpected current, heating, rail voltage or oscillation and investigate before increasing load. Remove input power before mating or unmating the Phoenix terminal.

Measure the raw 5 V rail, protected 5 V rail and 3.3 V rail before connecting DUTs. Useful points are **TP3 `/5V_BUCK`**, **TP4 `5V_SYS`** and **TP10 `3V3`**; use nearby ground points and `PCB/PROBE_MAP.csv`. The nominal buck set point is approximately 5.088 V; that is not a guaranteed connector voltage or a tolerance limit.

## Required checks

1. **Reset and enable safety.** Verify hub reset releases only after downstream 3.3 V is valid. Keep battery charging disabled so USB2514 PRTPWR is removed during reset. All four CH217A EN# nodes must stay high/off until hub control is valid. Repeat during brownout, input collapse and overvoltage recovery.
2. **Startup and inrush.** Test cold start, each port independently, all-four enable, `uhubctl` batch commands and repeated cycling with the four 220 µF port capacitors discharged. Combined adjustable switch limits can exceed the buck's 3.5 A rating. Reset default-off does not prove simultaneous-enable behavior. Timing-capacitor sites are DNP and provide no staggering. If experimenting with them, revalidate reset straps, turn-off and discharge timing.
3. **Regulation and transients.** At both 12 V and 24 V input, test no DUT load, hub only, each port at 1 A in turn, and two ports totaling 2 A. Observe startup, abrupt load application/removal, disconnect, supply ramp and collapse. Check ringing, oscillation, pulse-skipping and audible noise. The SCT regulator has no forced-PWM mode; calculations and example circuits do not prove this board's loop stability.
4. **Voltage and temperature.** At thermal steady state, measure voltage at the actual USB receptacles, including guard, switch, copper and contact losses. Record ambient conditions and the intended mounting/airflow arrangement. Check buck, inductor, capacitors, LDO, port switches and connectors at both input voltages. Repeat after changes to mounting or ventilation. CH217A's 110 mΩ maximum is specified at 25 °C, and the board does not inherit a reference PCB's thermal resistance. Reduce usable load if measurements require it.
5. **Fault behavior.** Using dummy loads only, test controlled overload/short-circuit waveforms, per-port overcurrent reporting, fault selectivity and hiccup recovery. Inspect inductor current for a saturation knee, overshoot and heating. For controlled raw-rail overvoltage ramps/steps, measure protected-rail overshoot, cutoff delay, recovery and downstream reset. ETA7014's screened static rising threshold is approximately **5.30–5.79 V**; it is not a hard 5.5 V or 6 V clamp. CH217A has a **6 V absolute maximum**. Do not expose real DUTs during fault qualification or infer transient safety from the static threshold. Combined 36–39 V input transients and a failed buck are outside the protection claim.
6. **USB and host control.** Verify individual overcurrent flags, independent on/off/cycle control and reliable re-enumeration with the actual host OS, cables and each DUT speed. Check actual USB2514B silicon revision and oscillator startup/drive. For A2 silicon, erratum Module 4 can miss a fast full-/low-speed detach/re-attach: apply more than 100 µs uninterrupted SE0 with the pull-up removed, or the applicable host Port Reset after host-commanded detach. Test normal long VBUS cycles as well. Consult the [Microchip errata](https://ww1.microchip.com/downloads/aemDocuments/documents/OTH/ProductDocuments/Errata/USB251xB-xBi-Errata-DS80000627D.pdf).
7. **Physical checks.** With actual hardware, verify connector mating/removal, cable retention, mounting strength and insulation under insertion forces. Physical fit and thermal tests are required even when CAD checks pass.

## Probe carefully

Use short ground-spring connections on power rails. Prefer measuring the rail instead of TP6 `/BUCK_FB`; feedback probing requires high input resistance and low capacitance. With the 53.6 kΩ upper divider and 0.8 V reference, a DC shunt probe shifts the set point by approximately 4.29 mV at 10 MΩ or 42.9 mV at 1 MΩ before other effects. Avoid long ground leads near the switch node.

Record measured conditions, limits and results for each built board. No completed hardware qualification, guaranteed thermal rating or USB signal-integrity certification is implied by this checklist.

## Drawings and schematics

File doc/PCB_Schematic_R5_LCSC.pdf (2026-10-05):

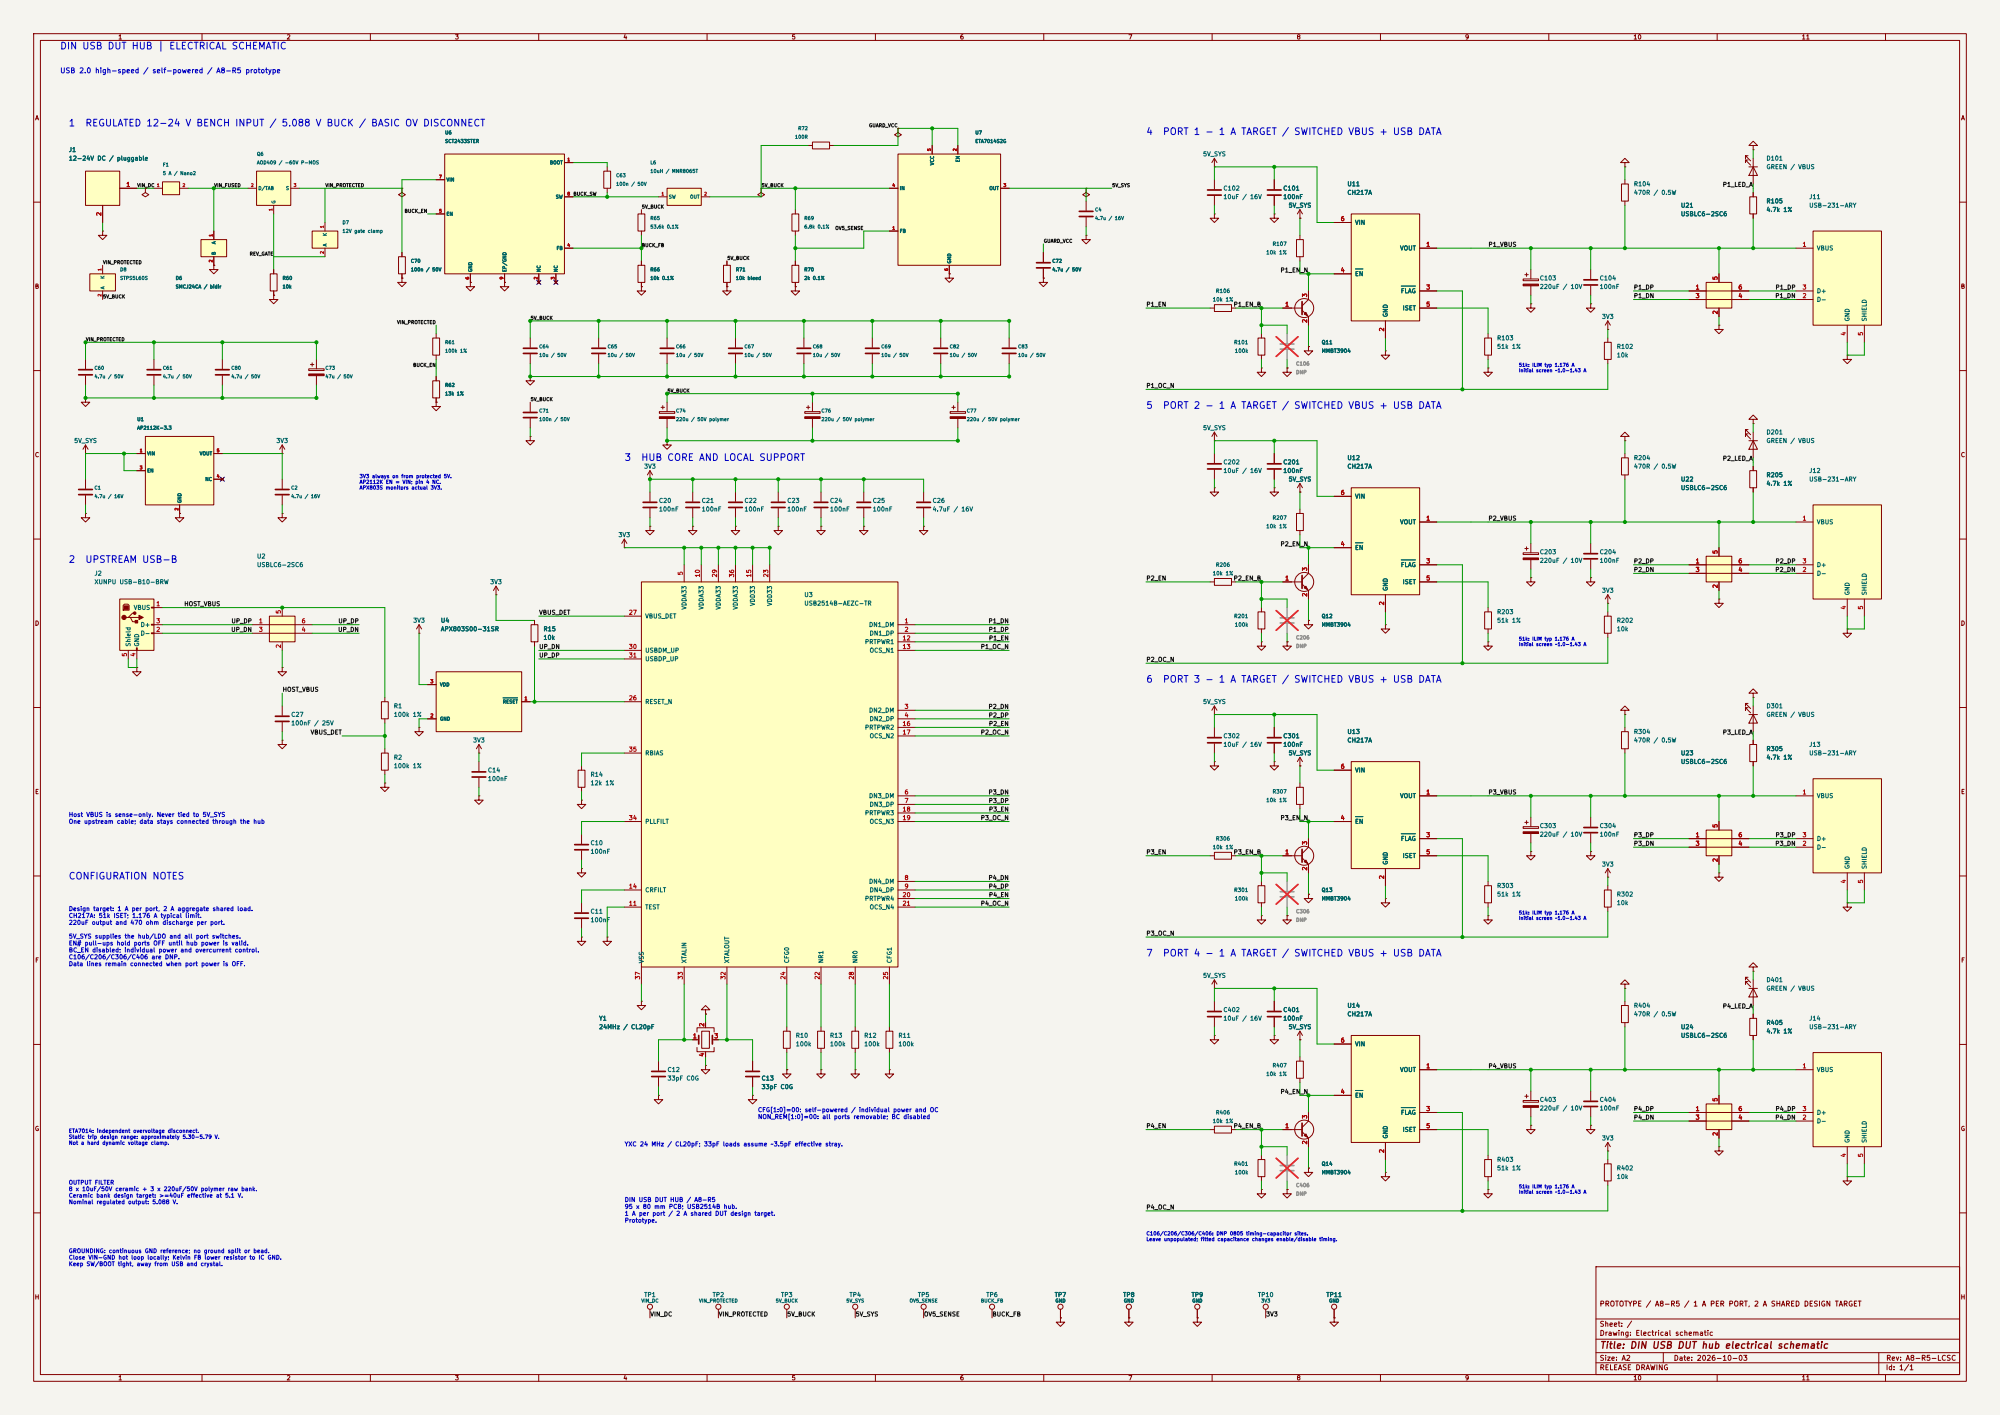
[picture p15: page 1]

DIN USB DUT HUB | ELECTRICAL SCHEMATIC

USB 2.0 high-speed / self-powered / A8-R5 prototype

1 REGULATED 12-24 V BENCH INPUT / 5.088 V BUCK / BASIC OV DISCONNECT

4 PORT 1 - 1 A TARGET / SWITCHED VBUS + USB DATA

6 VIN 7 SW 8 EP/GND

5 PORT 2 - 1 A TARGET / SWITCHED VBUS + USB DATA

3 HUB CORE AND LOCAL SUPPORT

3V3 always on from protected 5V. AP2112K EN = VIN; pin 4 NC. APX803S monitors actual 3V3.

HOST_VBUS Design target: 1 A per port, 2 A aggregate shared load. CH217A: 51k ISET; 1.176 A typical limit. 220uF output and 470 ohm discharge per port. 5V_SYS supplies the hub/LDO and all port switches. EN# pull-ups hold ports OFF until hub power is valid. BC_EN disabled; individual power and overcurrent control. C106/C206/C306/C406 are DNP. Data lines remain connected when port power is OFF.

Initial screen ~1.0-1.43 A 7 PORT 4 - 1 A TARGET / SWITCHED VBUS + USB DATA

6 PORT 3 - 1 A TARGET / SWITCHED VBUS + USB DATA

Host VBUS is sense-only. Never tied to 5V_SYS One upstream cable; data stays connected through the hub

Initial screen ~1.0-1.43 A DIN USB DUT HUB / A8-R5

C106/C206/C306/C406: DNP 0805 timing-capacitor sites. Leave unpopulated; fitted capacitance changes enable/disable timing. CFG[1:0]=00: self-powered / individual power and OC NON_REM[1:0]=00: all ports removable; BC disabled

YXC 24 MHz / CL20pF; 33pF loads assume ~3.5pF effective stray.

GROUNDING: continuous GND reference; no ground split or bead. Close VIN-GND hot loop locally; Kelvin FB lower resistor to IC GND. Keep SW/BOOT tight, away from USB and crystal. OUTPUT FILTER

95 x 80 mm PCB; USB2514B hub. 1 A per port / 2 A shared DUT design target.

PROTOTYPE / A8-R5 / 1 A PER PORT, 2 A SHARED DESIGN TARGET

Sheet: /
Drawing: Electrical schematic
Title: DIN USB DUT hub electrical schematic

Size: A2 | Rev: A8-R5-LCSC
RELEASE DRAWING | Id: 1/1

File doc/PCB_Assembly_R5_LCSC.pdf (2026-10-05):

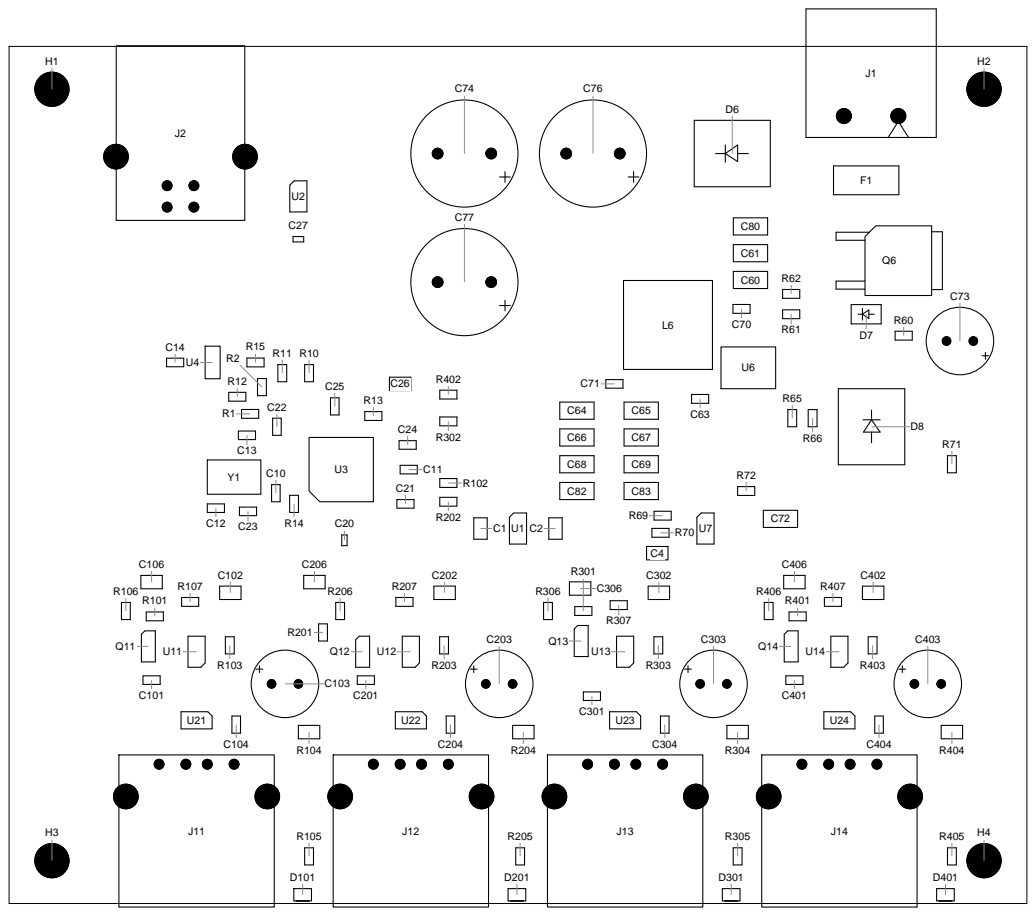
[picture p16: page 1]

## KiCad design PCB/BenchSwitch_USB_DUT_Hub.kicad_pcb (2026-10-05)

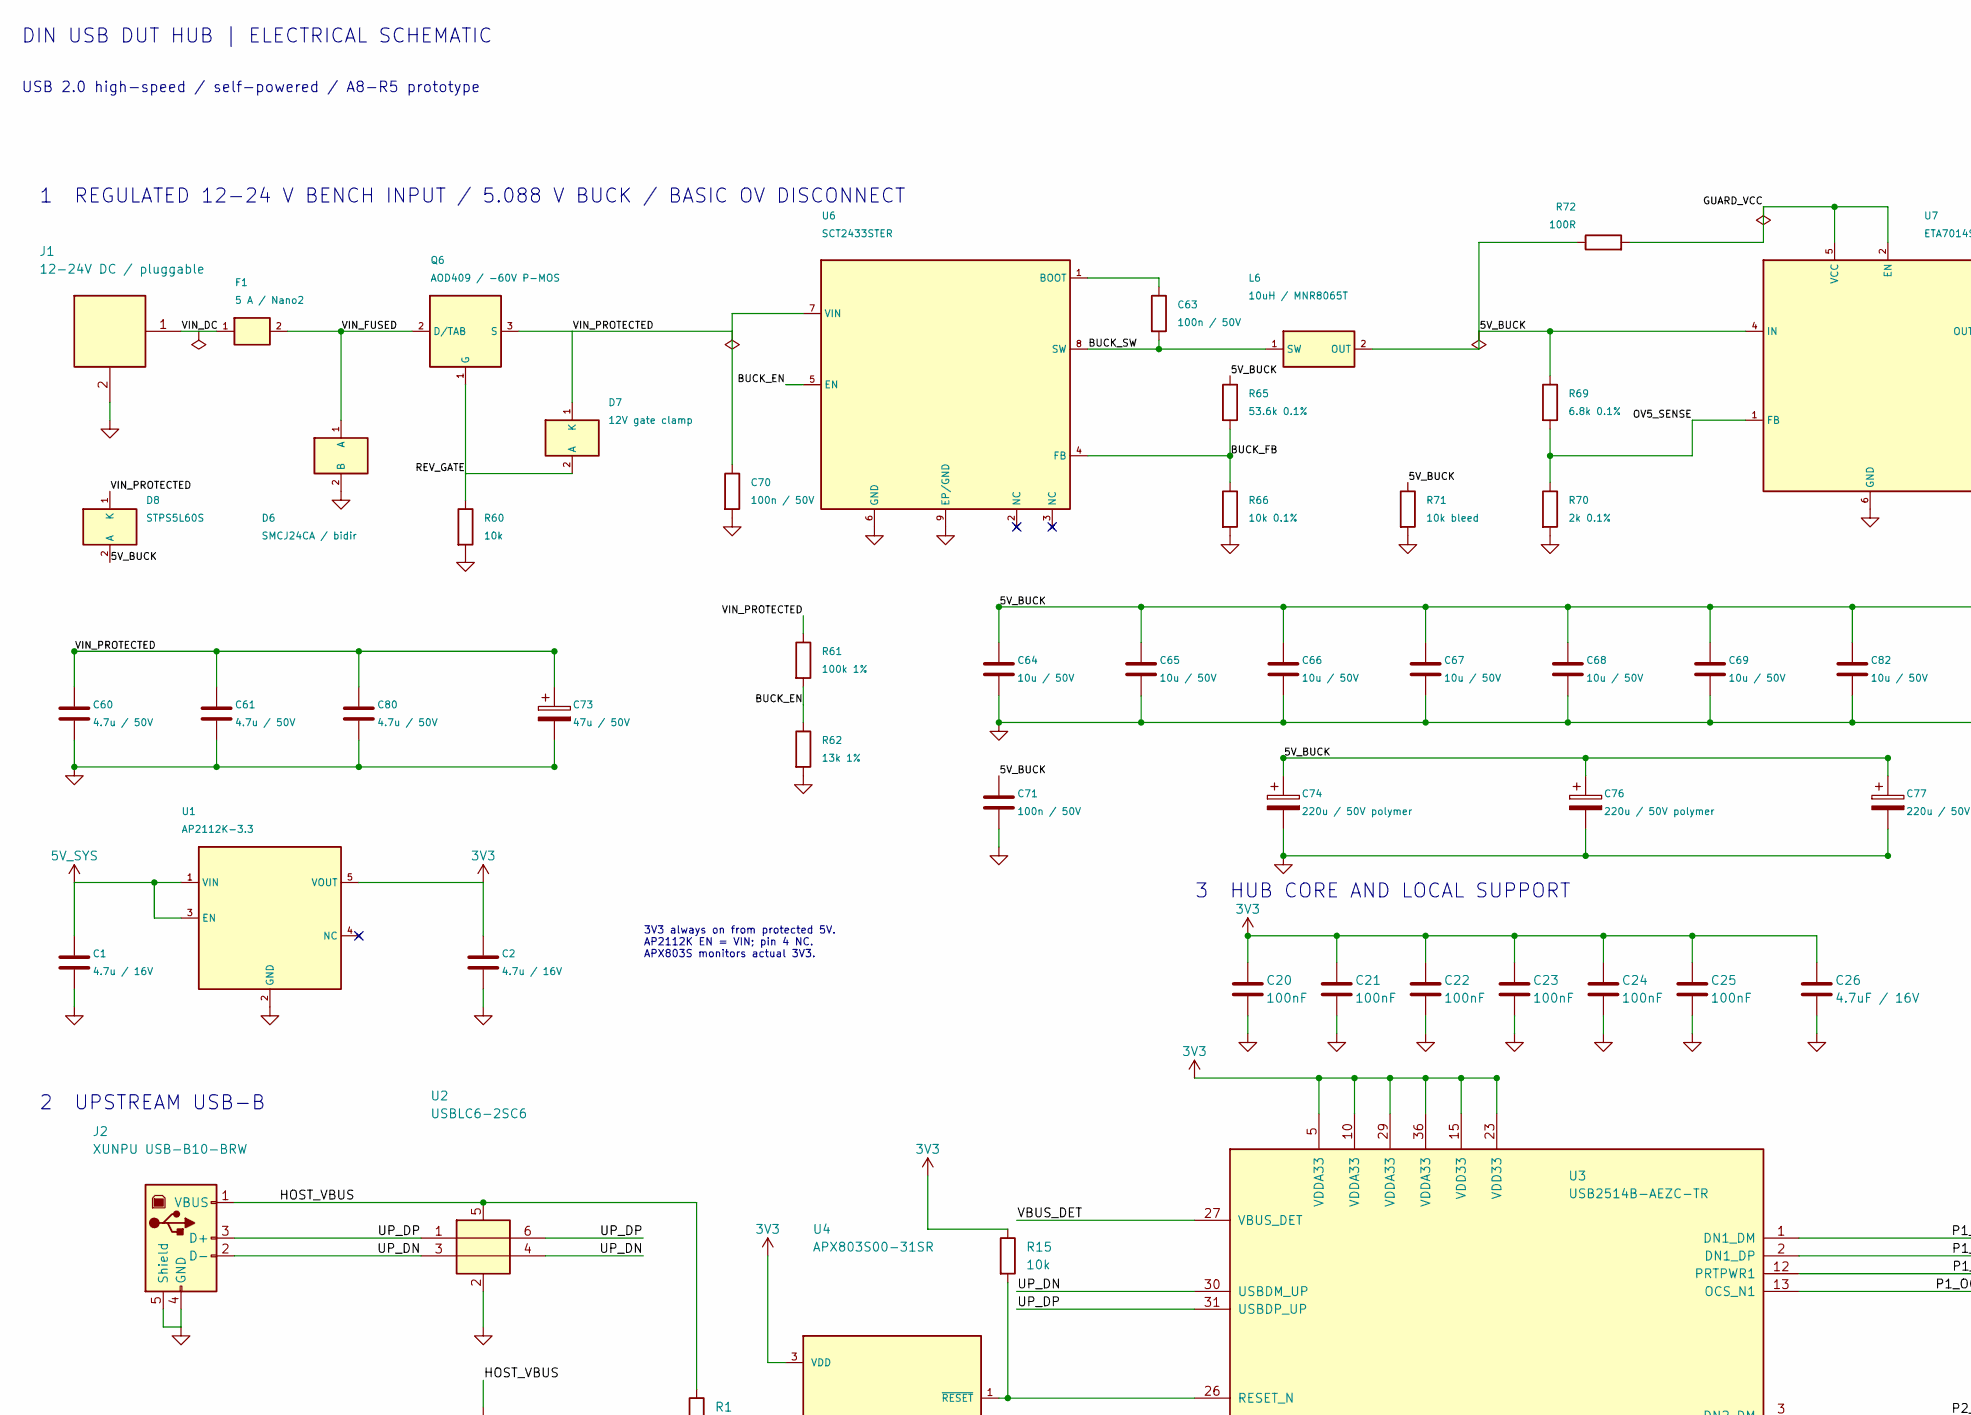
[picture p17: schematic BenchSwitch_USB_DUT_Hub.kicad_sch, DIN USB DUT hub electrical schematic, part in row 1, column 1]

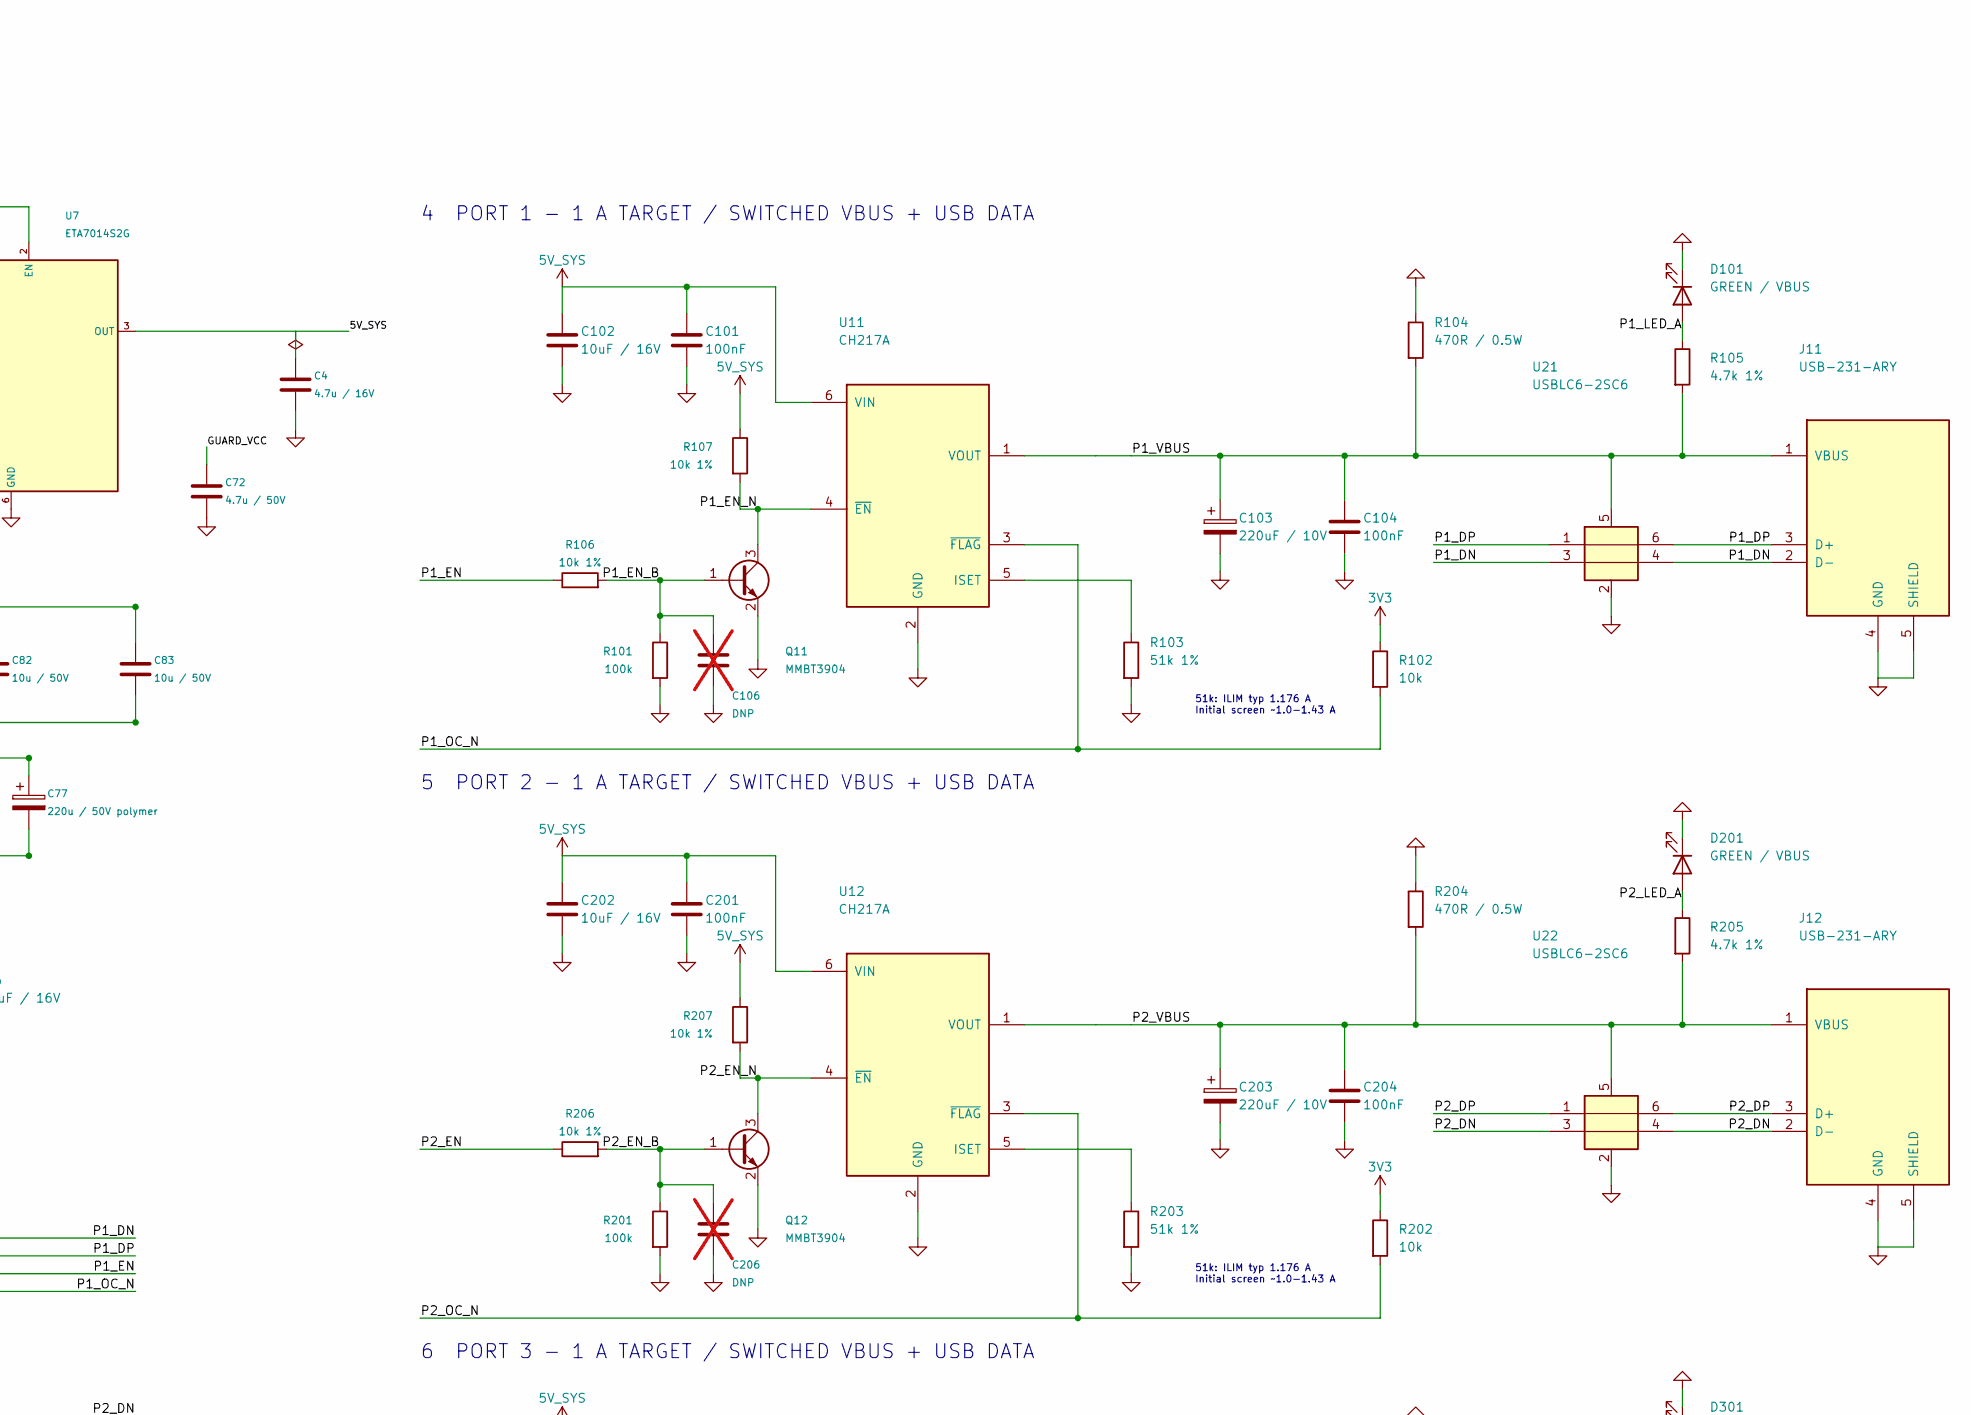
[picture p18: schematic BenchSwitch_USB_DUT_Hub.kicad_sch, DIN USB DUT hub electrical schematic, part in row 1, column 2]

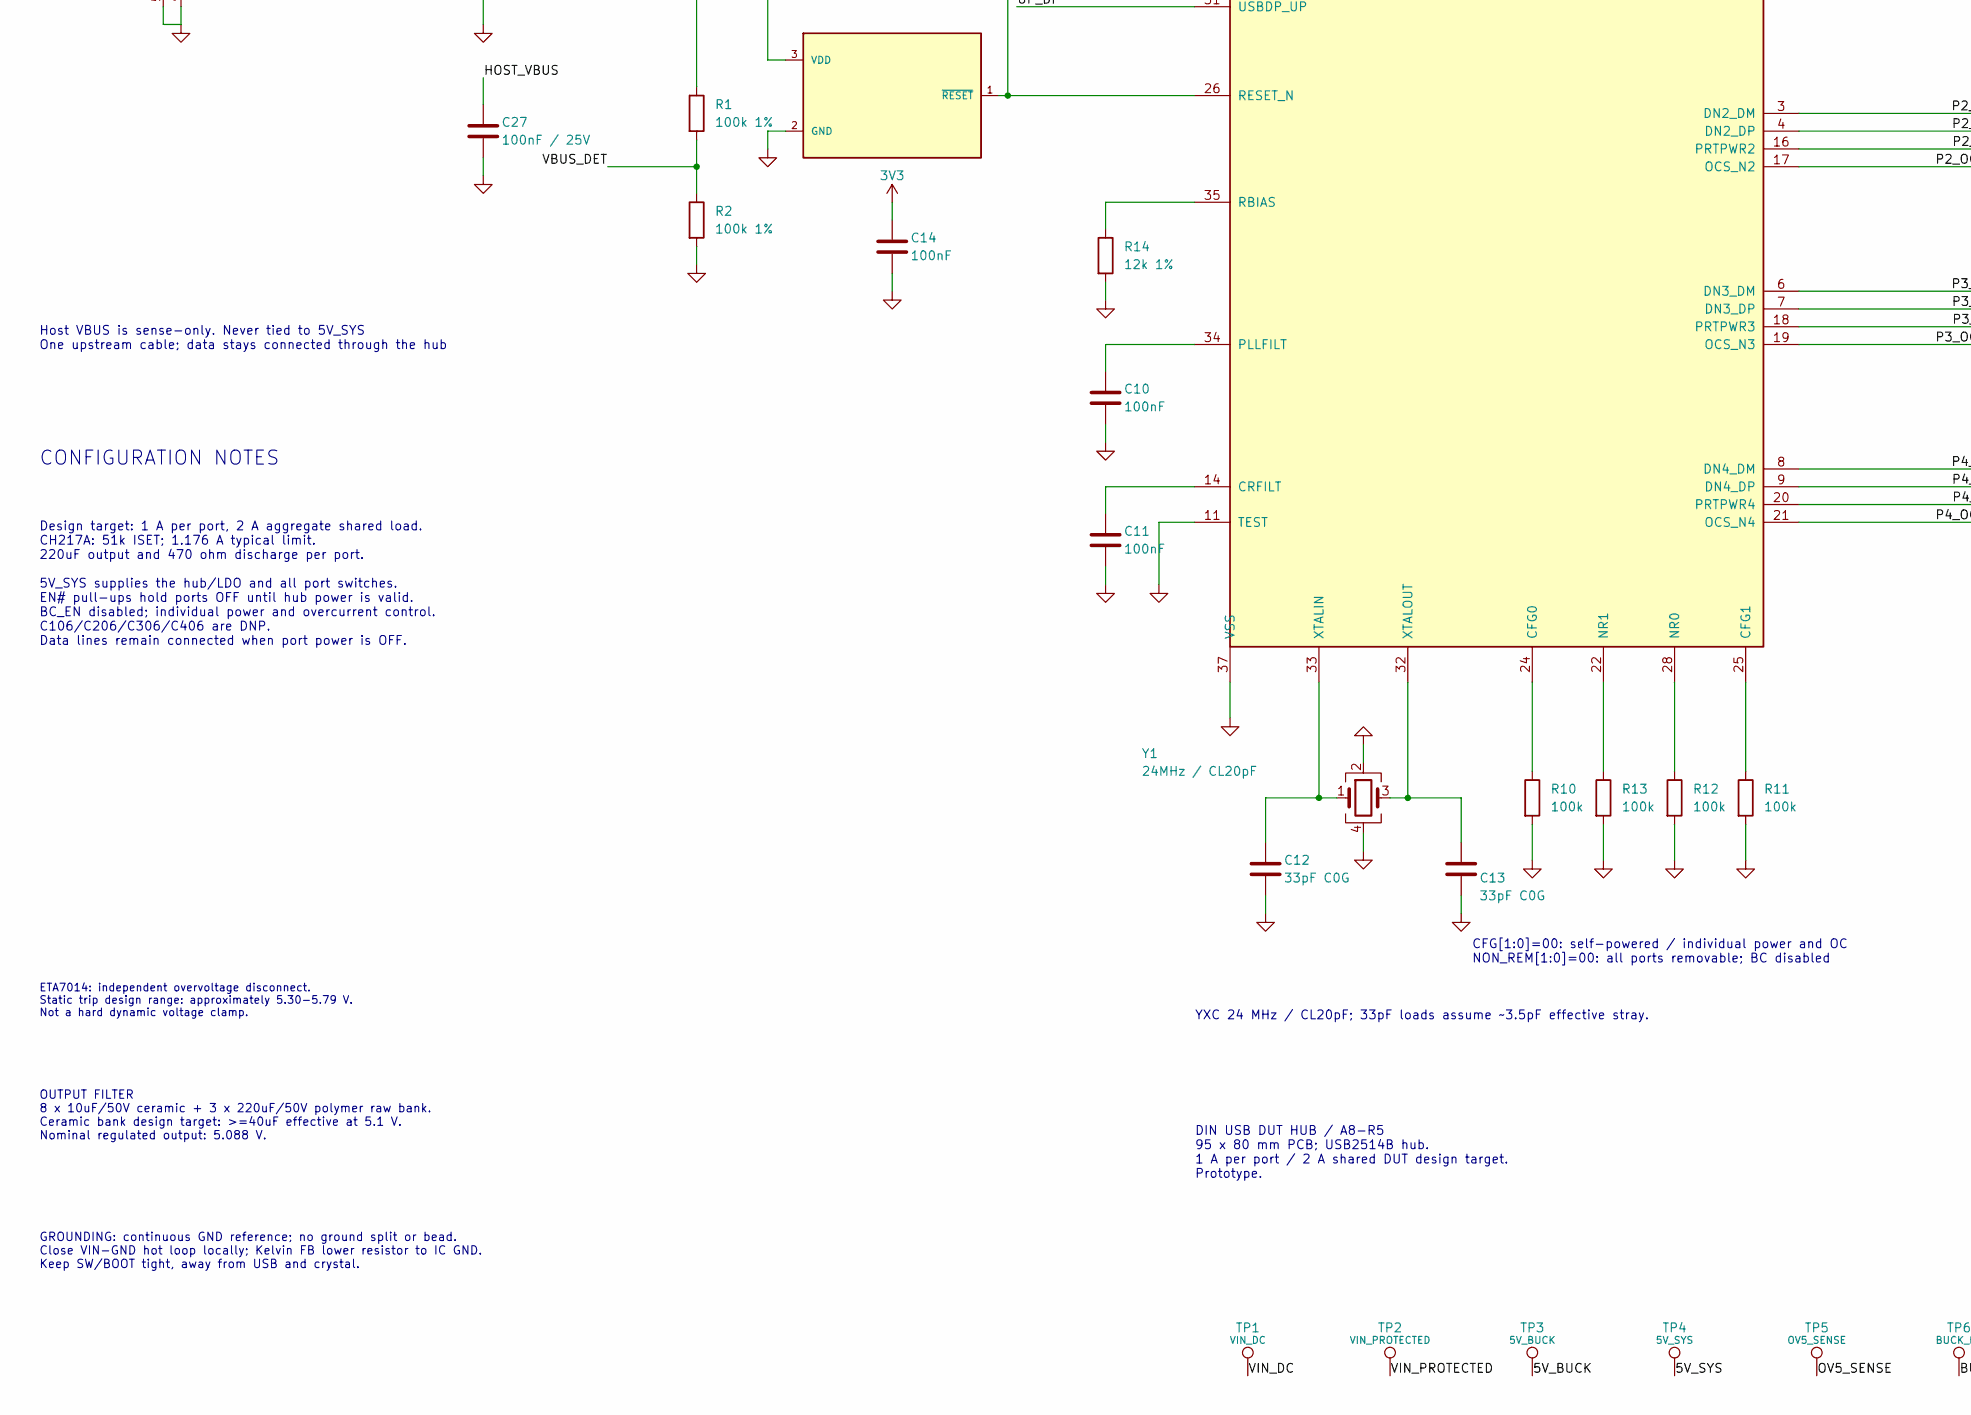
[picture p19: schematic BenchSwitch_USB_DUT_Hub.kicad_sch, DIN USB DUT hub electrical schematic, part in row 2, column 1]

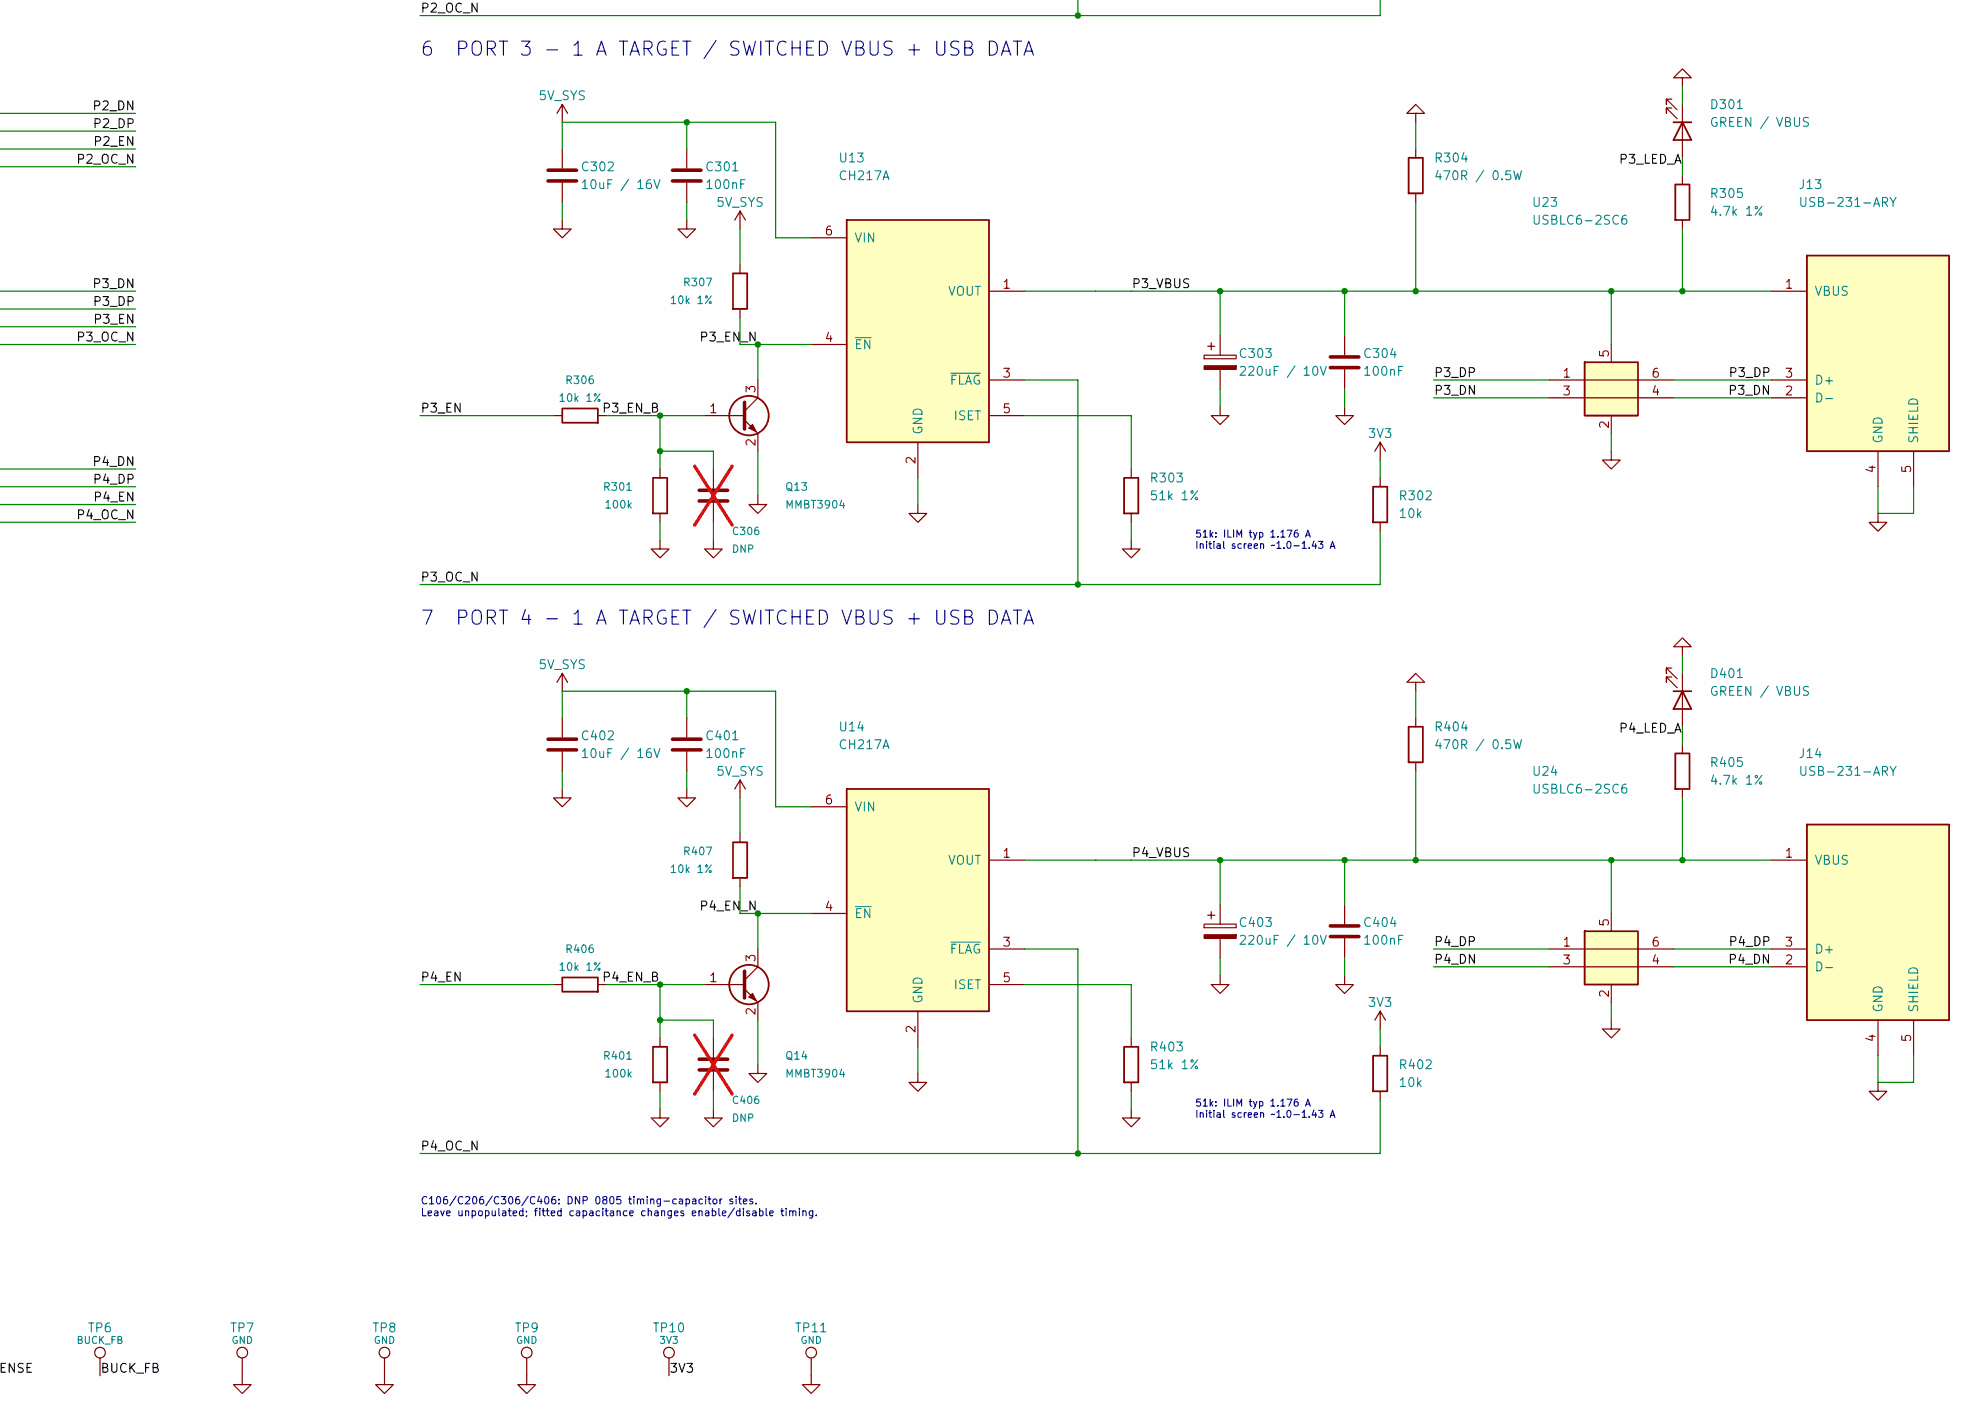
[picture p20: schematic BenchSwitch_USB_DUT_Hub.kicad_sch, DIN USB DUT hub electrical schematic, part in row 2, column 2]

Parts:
C1, C2, C4: 4.7u / 16V; C_0805_2012Metric; MPN 0805B475K160NT; LCSC C880382
C10, C11, C14, C21, C22, C23, C24, C25, C101, C104, C201, C204, C301, C304, C401, C404: 100nF; C_0603_1608Metric; Tolerance 10%; MPN CC0603KRX7R9BB104; LCSC C14663
C12, C13: 33pF C0G; C_0603_1608Metric; MPN CL10C330JB8NNNC; LCSC C1663
C20: 100nF; C_0402_1005Metric; Tolerance 10%; MPN CC0402KRX7R8BB104; LCSC C105883
C26: 4.7uF / 16V; C_0805_2012Metric; MPN 0805B475K160NT; LCSC C880382
C27: 100nF / 25V; C_0402_1005Metric; Tolerance 10%; MPN CC0402KRX7R8BB104; LCSC C105883
C60, C61, C72, C80: 4.7u / 50V; C_1206_3216Metric; MPN 1206B475K500NT; LCSC C29823
C63, C70: 100n / 50V; R_0603_1608Metric; MPN CC0603KRX7R9BB104; LCSC C14663
C64, C65, C66, C67, C68, C69, C82, C83: 10u / 50V; Samsung_CL31_1206; MPN CL31B106KBHNFNE; LCSC C913957
C71: 100n / 50V; C_0603_1608Metric; MPN CC0603KRX7R9BB104; LCSC C14663
C73: 47u / 50V; CP_Radial_D6.3mm_P2.50mm; MPN SPZ1HM470E08O00RAXXX; LCSC C122243
C74, C76, C77: 220u / 50V polymer; CP_Radial_D10.0mm_P5.00mm; MPN SPZ1HM221G12O00RAXXX; LCSC C2691846
C102, C202, C302, C402: 10uF / 16V; C_0805_2012Metric; Tolerance 10%; MPN CC0805KKX7R7BB106; LCSC C326595
C103, C203, C303, C403: 220uF / 10V; CP_Radial_D6.3mm_P2.50mm; Tolerance 20%; MPN ERS1AM221E11OT; LCSC C106640
C106, C206, C306, C406: DNP; C_0805_2012Metric; not fitted
D6: SMCJ24CA / bidir; D_SMC; MPN SMCJ24CA-13-F; LCSC C135155
D7: 12V gate clamp; D_SOD-123F; MPN BZT52H-C12,115; LCSC C282531
D8: STPS5L60S; D_SMC; MPN STPS5L60S; LCSC C140620
D101, D201, D301, D401: GREEN / VBUS; LED_LiteOn_LTST-S270KGKT_SideView; MPN LTST-S270KGKT; LCSC C125113
F1: 5 A / Nano2; Fuse_Littelfuse-NANO2-451_453; MPN 0451005.MRL; LCSC C48467
J1: 12-24V DC / pluggable; Phoenix_MSTBA_1757242_2pos_P5.08; MPN 1757242; LCSC C90074
J2: XUNPU USB-B10-BRW; XUNPU_USB_B10_BRW; MPN USB-B10-BRW; LCSC C720549
J11, J12, J13, J14: USB-231-ARY; XUNPU_USB_231_ARY; MPN USB-231-ARY; LCSC C720525
L6: 10uH / MNR8065T; Sunlord_SWPA8065S; MPN MNR8065T100MT; LCSC C18222125
Q6: AOD409 / -60V P-MOS; AOS_AOD409_TO252; MPN AOD409; LCSC C36220
Q11, Q12, Q13, Q14: MMBT3904; SOT-23; MPN MMBT3904LT1G; LCSC C81464
R1, R2: 100k 1%; R_0603_1608Metric; Tolerance 1%; MPN 0603WAF1003T5E; LCSC C25803
R10, R11, R12, R13, R101, R201, R301, R401: 100k; R_0603_1608Metric; Tolerance 1%; MPN 0603WAF1003T5E; LCSC C25803
R14: 12k 1%; R_0603_1608Metric; Tolerance 1%; MPN 0603WAF1202T5E; LCSC C22790
R15, R102, R202, R302, R402: 10k; R_0603_1608Metric; Tolerance 1%; MPN RC0603FR-0710KL; LCSC C98220
R60: 10k; R_0603_1608Metric; MPN RC0603FR-0710KL; LCSC C98220
R61: 100k 1%; R_0603_1608Metric; MPN 0603WAF1003T5E; LCSC C25803
R62: 13k 1%; R_0603_1608Metric; MPN 0603WAF1302T5E; LCSC C22797
R65: 53.6k 0.1%; R_0603_1608Metric; MPN ERA-3AEB5362V; LCSC C2074540
R66: 10k 0.1%; R_0603_1608Metric; MPN RT0603BRD0710KL; LCSC C95204
R69: 6.8k 0.1%; R_0603_1608Metric; MPN RT0603BRD076K8L; LCSC C861539
R70: 2k 0.1%; R_0603_1608Metric; MPN PTFR0603B2K00P9; LCSC C328425
R71: 10k bleed; R_0603_1608Metric; MPN RC0603FR-0710KL; LCSC C98220
R72: 100R; R_0603_1608Metric; MPN 0603WAF1000T5E; LCSC C22775
R103, R203, R303, R403: 51k 1%; R_0603_1608Metric; MPN 0603WAF5102T5E; LCSC C23196
R104, R204, R304, R404: 470R / 0.5W; R_0805_2012Metric; Tolerance 1%; MPN ERJ-P06F4700V; LCSC C441978
R105, R205, R305, R405: 4.7k 1%; R_0603_1608Metric; MPN 0603WAF4701T5E; LCSC C23162
R106, R107, R206, R207, R306, R307, R406, R407: 10k 1%; R_0603_1608Metric; Tolerance 1%; MPN RC0603FR-0710KL; LCSC C98220
TP1: VIN_DC; Probe_1.0mm
TP2: VIN_PROTECTED; Probe_1.0mm
TP3: 5V_BUCK; Probe_1.0mm
TP4: 5V_SYS; Probe_1.0mm
TP5: OV5_SENSE; Probe_1.0mm
TP6: BUCK_FB; Probe_0.4mm
TP7, TP8, TP9, TP11: GND; Probe_1.0mm
TP10: 3V3; Probe_1.0mm
U1: AP2112K-3.3; SOT-23-5; MPN AP2112K-3.3TRG1; LCSC C51118
U2, U21, U22, U23, U24: USBLC6-2SC6; SOT-23-6; MPN USBLC6-2SC6; LCSC C7519
U3: USB2514B-AEZC-TR; QFN-36-1EP_6x6mm_P0.5mm_EP3.7x3.7mm; MPN USB2514B-AEZC-TR; LCSC C16251
U4: APX803S00-31SR; Diodes_APX803S_SR_SOT23; MPN APX803S00-31SR-7; LCSC C2067620
U6: SCT2433STER; SCT2433_ESOP8; MPN SCT2433STER; LCSC C509399
U7: ETA7014S2G; SOT-23-6; MPN ETA7014S2G; LCSC C7465500
U11, U12, U13, U14: CH217A; SOT-23-6; MPN CH217A; LCSC C54973763
Y1: 24MHz / CL20pF; YXC_YSX531SL_5032; Tolerance See exact manufacturer grade; MPN XL1EL89CSI-111YLC-24M; LCSC C18214302

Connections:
3V3: C2.1, C14.1, C20.1, C21.1, C22.1, C23.1, C24.1, C25.1, C26.1, R15.1, R102.1, R202.1, R302.1, R402.1, TP10.1, U1.5 (VOUT), U3.5 (VDDA33), U3.10 (VDDA33), U3.15 (VDD33), U3.23 (VDD33), U3.29 (VDDA33), U3.36 (VDDA33), U4.3 (VDD)
5V_SYS: C1.1, C4.1, C101.1, C102.1, C201.1, C202.1, C301.1, C302.1, C401.1, C402.1, R107.1, R207.1, R307.1, R407.1, TP4.1, U1.1 (VIN), U1.3 (EN), U7.3 (OUT), U11.6 (VIN), U12.6 (VIN), U13.6 (VIN), U14.6 (VIN)
/5V_BUCK: C64.1, C65.1, C66.1, C67.1, C68.1, C69.1, C71.1, C74.1, C76.1, C77.1, C82.1, C83.1, D8.2 (A), L6.2 (OUT), R65.1, R69.1, R71.1, R72.1, TP3.1, U7.4 (IN)
/BUCK_EN: R61.2, R62.1, U6.5 (EN)
/BUCK_FB: R65.2, R66.1, TP6.1, U6.4 (FB)
/BUCK_SW: C63.2, L6.1 (SW), U6.8 (SW)
/GUARD_VCC: C72.1, R72.2, U7.2 (EN), U7.5 (VCC)
/HOST_VBUS: C27.1, J2.1 (VBUS), R1.1, U2.5 (VBUS)
/OV5_SENSE: R69.2, R70.1, TP5.1, U7.1 (FB)
/P1_DN: J11.2 (D-), U3.1 (DN1_DM), U21.3 (I/O2), U21.4 (I/O2)
/P1_DP: J11.3 (D+), U3.2 (DN1_DP), U21.1 (I/O1), U21.6 (I/O1)
/P1_EN: R106.1, U3.12 (PRTPWR1)
/P1_EN_B: C106.1, Q11.1 (B), R101.1, R106.2
/P1_EN_N: Q11.3 (C), R107.2, U11.4 (~EN)
/P1_LED_A: D101.2 (A), R105.1
/P1_OC_N: R102.2, U3.13 (OCS_N1), U11.3 (~FLAG)
/P1_VBUS: C103.1, C104.1, J11.1 (VBUS), R104.2, R105.2, U11.1 (VOUT), U21.5 (VBUS)
/P2_DN: J12.2 (D-), U3.3 (DN2_DM), U22.3 (I/O2), U22.4 (I/O2)
/P2_DP: J12.3 (D+), U3.4 (DN2_DP), U22.1 (I/O1), U22.6 (I/O1)
/P2_EN: R206.1, U3.16 (PRTPWR2)
/P2_EN_B: C206.1, Q12.1 (B), R201.1, R206.2
/P2_EN_N: Q12.3 (C), R207.2, U12.4 (~EN)
/P2_LED_A: D201.2 (A), R205.1
/P2_OC_N: R202.2, U3.17 (OCS_N2), U12.3 (~FLAG)
/P2_VBUS: C203.1, C204.1, J12.1 (VBUS), R204.2, R205.2, U12.1 (VOUT), U22.5 (VBUS)
/P3_DN: J13.2 (D-), U3.6 (DN3_DM), U23.3 (I/O2), U23.4 (I/O2)
/P3_DP: J13.3 (D+), U3.7 (DN3_DP), U23.1 (I/O1), U23.6 (I/O1)
/P3_EN: R306.1, U3.18 (PRTPWR3)
/P3_EN_B: C306.1, Q13.1 (B), R301.1, R306.2
/P3_EN_N: Q13.3 (C), R307.2, U13.4 (~EN)
/P3_LED_A: D301.2 (A), R305.1
/P3_OC_N: R302.2, U3.19 (OCS_N3), U13.3 (~FLAG)
/P3_VBUS: C303.1, C304.1, J13.1 (VBUS), R304.2, R305.2, U13.1 (VOUT), U23.5 (VBUS)
/P4_DN: J14.2 (D-), U3.8 (DN4_DM), U24.3 (I/O2), U24.4 (I/O2)
/P4_DP: J14.3 (D+), U3.9 (DN4_DP), U24.1 (I/O1), U24.6 (I/O1)
/P4_EN: R406.1, U3.20 (PRTPWR4)
/P4_EN_B: C406.1, Q14.1 (B), R401.1, R406.2
/P4_EN_N: Q14.3 (C), R407.2, U14.4 (~EN)
/P4_LED_A: D401.2 (A), R405.1
/P4_OC_N: R402.2, U3.21 (OCS_N4), U14.3 (~FLAG)
/P4_VBUS: C403.1, C404.1, J14.1 (VBUS), R404.2, R405.2, U14.1 (VOUT), U24.5 (VBUS)
/REV_GATE: D7.2 (A), Q6.1 (G), R60.1
/UP_DN: J2.2 (D-), U2.3 (I/O2), U2.4 (I/O2), U3.30 (USBDM_UP)
/UP_DP: J2.3 (D+), U2.1 (I/O1), U2.6 (I/O1), U3.31 (USBDP_UP)
/VBUS_DET: R1.2, R2.1, U3.27 (VBUS_DET)
/VIN_DC: F1.1, J1.1 (VIN_DC), TP1.1
/VIN_FUSED: D6.1 (A), F1.2, Q6.2 (D/TAB)
/VIN_PROTECTED: C60.1, C61.1, C70.1, C73.1, C80.1, D7.1 (K), D8.1 (K), Q6.3 (S), R61.1, TP2.1, U6.7 (VIN)
GND: C1.2, C2.2, C4.2, C10.2, C11.2, C12.2, C13.2, C14.2, C20.2, C21.2, C22.2, C23.2, C24.2, C25.2, C26.2, C27.2, C60.2, C61.2, C64.2, C65.2, C66.2, C67.2, C68.2, C69.2, C70.2, C71.2, C72.2, C73.2, C74.2, C76.2, C77.2, C80.2, C82.2, C83.2, C101.2, C102.2, C103.2, C104.2, C106.2, C201.2, C202.2, C203.2, C204.2, C206.2, C301.2, C302.2, C303.2, C304.2, C306.2, C401.2, C402.2, C403.2, C404.2, C406.2, D6.2 (B), D101.1 (K), D201.1 (K), D301.1 (K), D401.1 (K), J1.2 (GND), J2.4 (GND), J2.5 (Shield), J11.4 (GND), J11.5 (SHIELD), J12.4 (GND), J12.5 (SHIELD), J13.4 (GND), J13.5 (SHIELD), J14.4 (GND), J14.5 (SHIELD), Q11.2 (E), Q12.2 (E), Q13.2 (E), Q14.2 (E), R2.2, R10.2, R11.2, R12.2, R13.2, R14.2, R60.2, R62.2, R66.2, R70.2, R71.2, R101.2, R103.2, R104.1, R201.2, R203.2, R204.1, R301.2, R303.2, R304.1, R401.2, R403.2, R404.1, TP7.1, TP8.1, TP9.1, TP11.1, U1.2 (GND), U2.2 (GND), U3.11 (TEST), U3.37 (VSS), U4.2 (GND), U6.6 (GND), U6.9 (EP/GND), U7.6 (GND), U11.2 (GND), U12.2 (GND), U13.2 (GND), U14.2 (GND), U21.2 (GND), U22.2 (GND), U23.2 (GND), U24.2 (GND), Y1.2, Y1.4
unnamed: R10.1, U3.24 (CFG0)
unnamed: R11.1, U3.25 (CFG1)
unnamed: C11.1, U3.14 (CRFILT)
unnamed: R12.1, U3.28 (NR0)
unnamed: R13.1, U3.22 (NR1)
unnamed: C10.1, U3.34 (PLLFILT)
unnamed: R14.1, U3.35 (RBIAS)
unnamed: R15.2, U3.26 (RESET_N), U4.1 (~RESET)
unnamed: C12.1, U3.33 (XTALIN), Y1.1
unnamed: C13.1, U3.32 (XTALOUT), Y1.3
unnamed: C63.1, U6.1 (BOOT)
unnamed: R103.1, U11.5 (ISET)
unnamed: R203.1, U12.5 (ISET)
unnamed: R303.1, U13.5 (ISET)
unnamed: R403.1, U14.5 (ISET)

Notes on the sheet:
DIN USB DUT HUB | ELECTRICAL SCHEMATIC
USB 2.0 high-speed / self-powered / A8-R5 prototype
1 REGULATED 12-24 V BENCH INPUT / 5.088 V BUCK / BASIC OV DISCONNECT
2 UPSTREAM USB-B
Host VBUS is sense-only. Never tied to 5V_SYS One upstream cable; data stays connected through the hub
3 HUB CORE AND LOCAL SUPPORT
CFG[1:0]=00: self-powered / individual power and OC NON_REM[1:0]=00: all ports removable; BC disabled
4 PORT 1 - 1 A TARGET / SWITCHED VBUS + USB DATA
5 PORT 2 - 1 A TARGET / SWITCHED VBUS + USB DATA
6 PORT 3 - 1 A TARGET / SWITCHED VBUS + USB DATA
7 PORT 4 - 1 A TARGET / SWITCHED VBUS + USB DATA
CONFIGURATION NOTES
Design target: 1 A per port, 2 A aggregate shared load. CH217A: 51k ISET; 1.176 A typical limit. 220uF output and 470 ohm discharge per port. 5V_SYS supplies the hub/LDO and all port switches. EN# pull-ups hold ports OFF until hub power is valid. BC_EN disabled; individual power and overcurrent con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
DIN USB DUT HUB / A8-R5 95 x 80 mm PCB; USB2514B hub. 1 A per port / 2 A shared DUT design target. Prototype.
YXC 24 MHz / CL20pF; 33pF loads assume ~3.5pF effective stray.
ETA7014: independent overvoltage disconnect. Static trip design range: approximately 5.30-5.79 V. Not a hard dynamic voltage clamp.
OUTPUT FILTER 8 x 10uF/50V ceramic + 3 x 220uF/50V polymer raw bank. Ceramic bank design target: >=40uF effective at 5.1 V. Nominal regulated output: 5.088 V.
GROUNDING: continuous GND reference; no ground split or bead. Close VIN-GND hot loop locally; Kelvin FB lower resistor to IC GND. Keep SW/BOOT tight, away from USB and crystal.
51k: ILIM typ 1.176 A Initial screen ~1.0-1.43 A
C106/C206/C306/C406: DNP 0805 timing-capacitor sites. Leave unpopulated; fitted capacitance changes enable/disable timing.
3V3 always on from protected 5V. AP2112K EN = VIN; pin 4 NC. APX803S monitors actual 3V3.

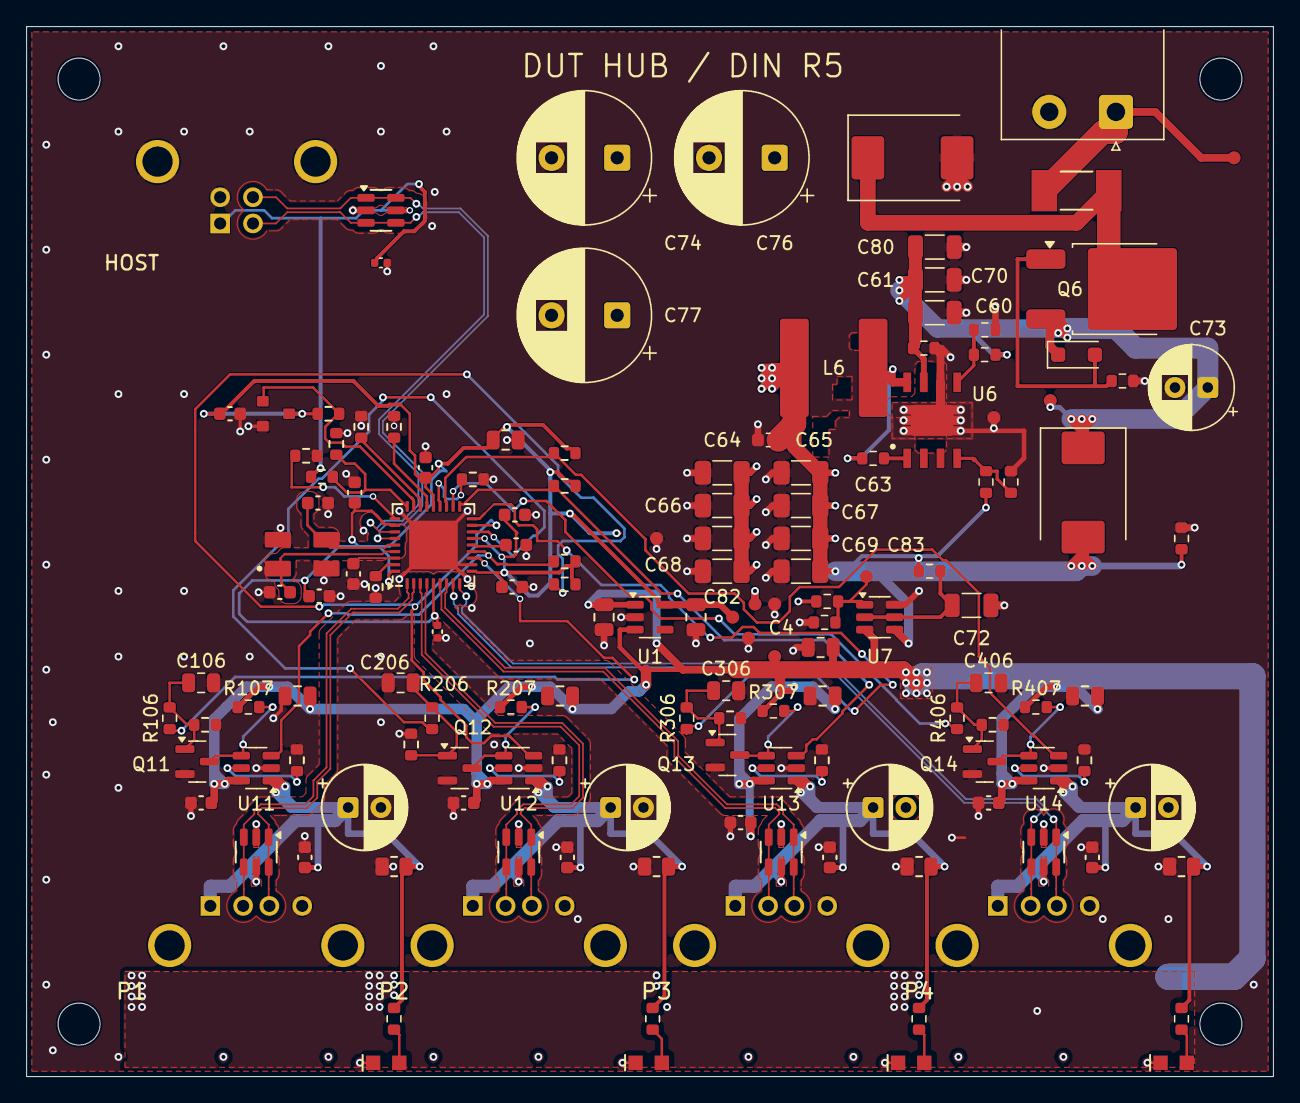
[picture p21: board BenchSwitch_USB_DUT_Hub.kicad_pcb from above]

Board: 4 copper layers, 95.0 x 80.0 mm, 150 parts (0 on the bottom side), 64 nets.

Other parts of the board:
H1, H2, H3, H4: M3 / 3.2mm NPTH; MountingHole_3.2mm_Enclosure_Post
